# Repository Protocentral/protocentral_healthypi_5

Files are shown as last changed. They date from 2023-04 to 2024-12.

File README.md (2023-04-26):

# HealthyPi 5 

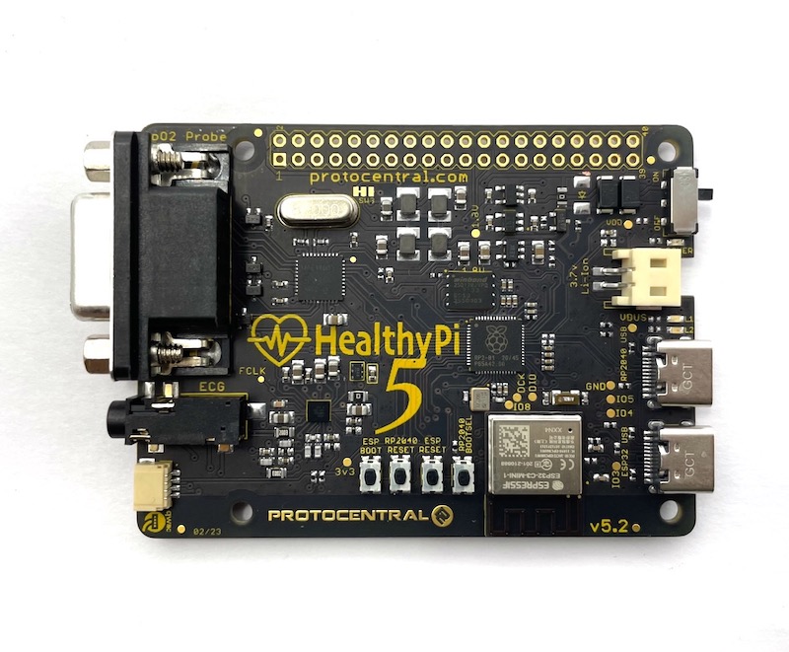
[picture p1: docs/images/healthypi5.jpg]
HealthyPi 5


Don't have one? You can pre-order now at [Crowd Supply](https://www.crowdsupply.com/protocentral/healthypi-5)

HealthyPi 5 is the latest evolution of the HealthyPi series. It is a robust, feature-rich, open-source development board that allows you to explore many different biosignals with minimal effort. Whether you need a simple monitor for a specific vital sign or a complete health-sensor platform, HealthyPi 5 is an extensible solution to to your health-data challenges. Out of the box, it can handle electrocardiogram (ECG), respiration, photoplethysmography (PPG), oxygen saturation (SpO₂), and body temperature data. And it’s easy to upgrade as well! Using the Qwiic connectors on the Pro-Carrier Board, you can leverage external sensor modules to capture and analyze additional biosignals, such as galvanic skin response (GSR), electroencephalogram (EEG), and electromyogram (EMG) data.

## Features

* RP2040 dual-core ARM Cortex M0 microcontroller
* ESP32C3 RISC-V module with BLE and Wi-Fi support
* MAX30001 analog front end for ECG and respiration measurement
* AFE4400 analog front end for PPG
* MAX30205 temperature sensor via onboard Qwiic/I²C connectors
* 40-pin Raspberry Pi HAT connector (also used to connect our Display Add-On Module)
* 1x USB Type-C connector for communication with a computer and programming the RP2040
* 1x USB Type-C connector for programming and debugging the ESP32 module
* Onboard MicroSD card slot
* On-board Li-Ion battery management with charging through USB

## Repository Contents

* /gui - Processing GUI for HealthyPi 5
* /hardware - Eagle design files (.brd, .sch, pdfs)
* /python - Python scripts for HealthyPi 5 (_Work in Progress_)
* If you're looking for the firmware for the HealthyPi 5, it's located in its own repository [here](https://github.com/Protocentral/protocentral_healthypi_5_firmware).

## License Information

This product is open source! Please see the LICENSE.md file for more information.

## Getting Started
_Getting Started Guide coming soon..._

## License Information

License

This product is open source! Both, our hardware and software are open source and licensed under the following licenses:

Hardware
---------

**All hardware is released under the [CERN-OHL-P v2](https://ohwr.org/cern_ohl_p_v2.txt)** license.

Copyright CERN 2020.

This source describes Open Hardware and is licensed under the CERN-OHL-P v2.

You may redistribute and modify this documentation and make products
using it under the terms of the CERN-OHL-P v2 (https:/cern.ch/cern-ohl).
This documentation is distributed WITHOUT ANY EXPRESS OR IMPLIED
WARRANTY, INCLUDING OF MERCHANTABILITY, SATISFACTORY QUALITY
AND FITNESS FOR A PARTICULAR PURPOSE. Please see the CERN-OHL-P v2
for applicable conditions

Software
--------

**All software is released under the MIT License(http://opensource.org/licenses/MIT).**

THE SOFTWARE IS PROVIDED "AS IS", WITHOUT WARRANTY OF ANY KIND, EXPRESS OR IMPLIED, INCLUDING BUT NOT LIMITED TO THE WARRANTIES OF MERCHANTABILITY, FITNESS FOR A PARTICULAR PURPOSE AND NONINFRINGEMENT. IN NO EVENT SHALL THE AUTHORS OR COPYRIGHT HOLDERS BE LIABLE FOR ANY CLAIM, DAMAGES OR OTHER LIABILITY, WHETHER IN AN ACTION OF CONTRACT, TORT OR OTHERWISE, ARISING FROM, OUT OF OR IN CONNECTION WITH THE SOFTWARE OR THE USE OR OTHER DEALINGS IN THE SOFTWARE.

Documentation
-------------
**All documentation is released under [Creative Commons Share-alike 4.0 International](http://creativecommons.org/licenses/by-sa/4.0/).**


You are free to:

* Share — copy and redistribute the material in any medium or format
* Adapt — remix, transform, and build upon the material for any purpose, even commercially.
The licensor cannot revoke these freedoms as long as you follow the license terms.

Under the following terms:

* Attribution — You must give appropriate credit, provide a link to the license, and indicate if changes were made. You may do so in any reasonable manner, but not in any way that suggests the licensor endorses you or your use.
* ShareAlike — If you remix, transform, or build upon the material, you must distribute your contributions under the same license as the original.

Please check [*LICENSE.md*](LICENSE.md) for detailed license descriptions.

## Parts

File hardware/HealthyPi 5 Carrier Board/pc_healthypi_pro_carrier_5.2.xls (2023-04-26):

healthpi_pro_carrier
Qty | Value | Parts | Package
2 | 100n | C3, C4 | C0402
2 | 100nF | C8, C11 | C0402
4 | 4.7u | C1, C2, C14, C16 | C0805
1 | 0R | R77 | R0805
2 | 10K | R7, R33 | R0402
2 | 5.1K | R3, R4 | R0402
3 | DNP | R9, R10, R11 | R0402
1 | INDUCTOR-82153C | U$45 | INDUCTOR-8200
1 | ISOUSB111DWXR | U$1 | SSOP-16-5.85X7.5
1 | NXJ2S0505MC | U$5 | NXJ2S0505MC
6 | PESD0402-0402 | D1, D2, D3, D4, D5, D6 | 402
1 | PIN20X2 | K1 | PIN_20X2
6 | QWIIC_RIGHT_ANGLE | J1, J2, J3, J5, J6, J7 | JST04_1MM_RA
5 | TBD | R1, R2, R5, R6, R8 | R0402
1 | TCR2EF33,LM(CT | U9 | SOT23-5
1 | USB4105-GF-A | J4 | USB-C-16P

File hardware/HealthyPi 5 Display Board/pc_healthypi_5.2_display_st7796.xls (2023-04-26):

pc_healthypi_5.2_display
Qty | Value | Parts | Package
1 | 100nF | C5 | C0402
2 | 10uF | C3, C4 | 0805-NO
1 | 1uF | C1 | 0805-NO
1 | 0R | R4 | R0402
1 | 0R | R7 | R0805
1 | 100K | R5 | 0805-NO
2 | 10K | R10, R12 | R0402
1 | 1K | R9 | R0402
3 | 1k | R8, R21, R44 | 402
2 | 330R | R2, R3 | R0402
1 | BC847 | T1 | SOT23-BEC
1 | BLUE | POWER1 | CHIPLED_0603
3 | DNP | R1, R6, R11 | R0402
1 | FPC40 | U$10 | FPC40PIN
1 | MEM2051-00-195-00-A | J1 | GCT_MEM2051-00-195-00-A
1 | NAV_SWITCH | S1 | NAV_SWITCH
1 | OS102011MA1QN1 | S3 | OS102011MA1QN1
1 | PIN20X2SMT | K1 | 20X2SMT
1 | RED | CHG2 | CHIPLED_0603

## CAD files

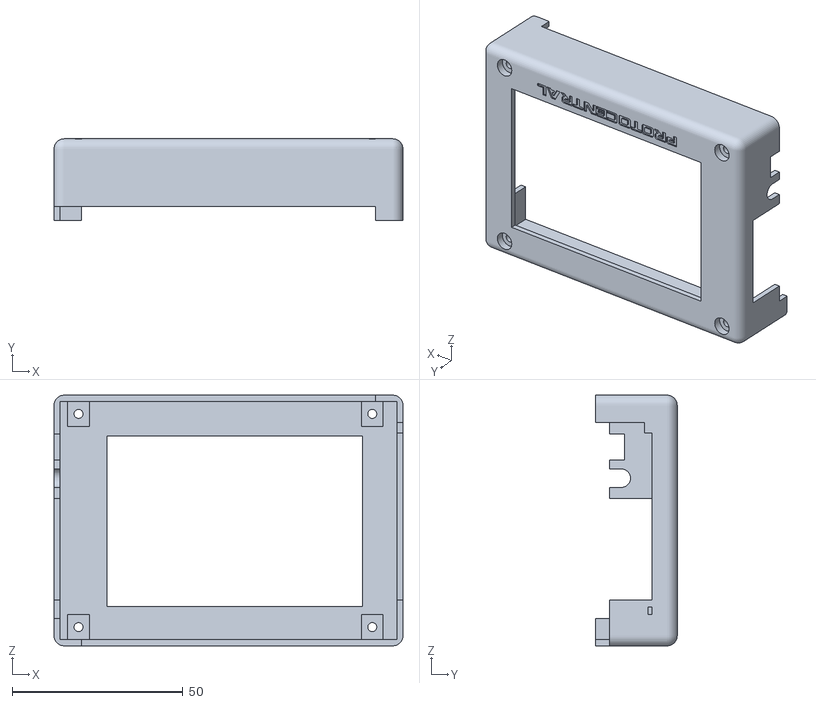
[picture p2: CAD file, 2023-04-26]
hardware/HealthyPi 5 Enclosure/HealthyPi 5 - Enclosure - Top.stl
102.3 x 23.9 x 73.5

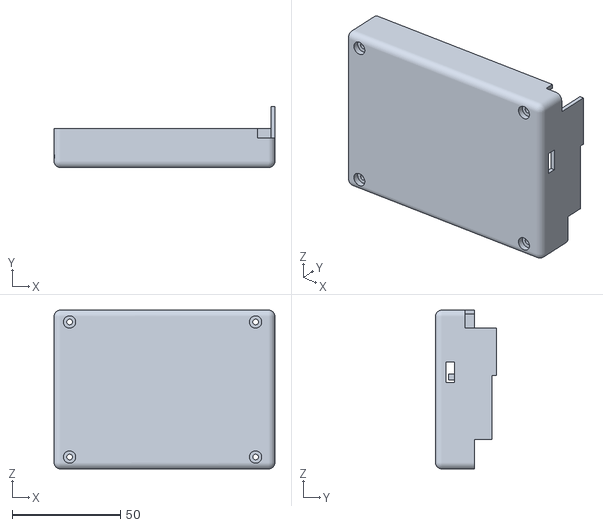
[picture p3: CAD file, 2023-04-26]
hardware/HealthyPi 5 Enclosure/HealthyPi 5 - Enclosure - Bottom.stl
102.3 x 28.3 x 73.5

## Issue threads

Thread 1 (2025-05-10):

PPG sample rate

selfinmotion, 2025-05-10:
What is the maximum sample rate for capture of PPG data this board is capable of? It seems to be missing from the specifications. Thank you.

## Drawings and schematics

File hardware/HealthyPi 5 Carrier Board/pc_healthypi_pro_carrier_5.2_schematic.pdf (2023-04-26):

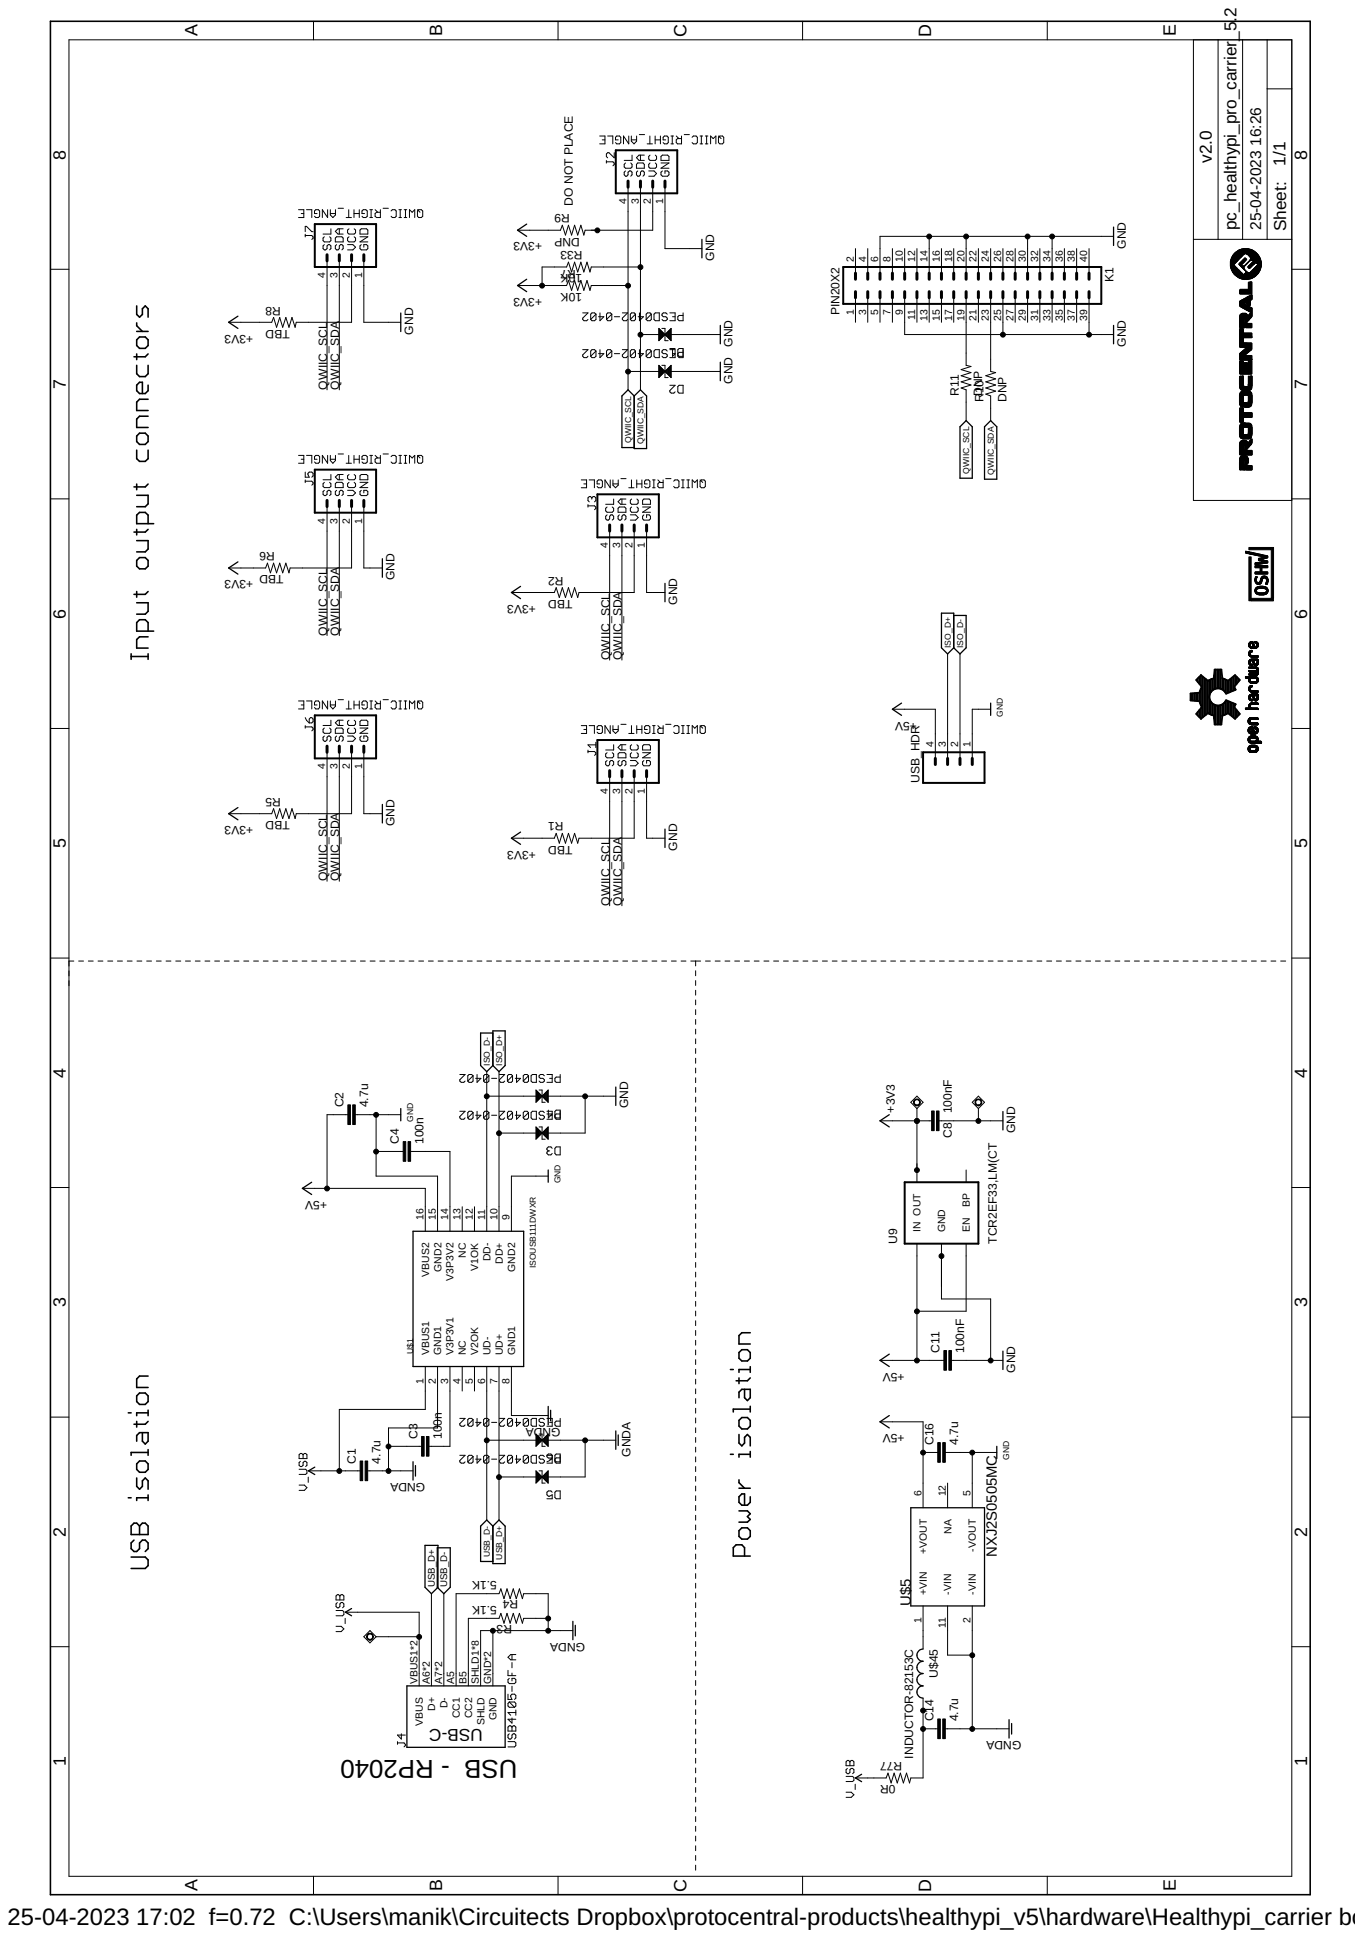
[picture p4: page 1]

25-04-2023 17:02 f=0.72 C:\Users\manik\Circuitects Dropbox\protocentral-products\healthypi_v5\hardware\Healthypi_carrier board\Carrier main board\pc_healthypi_pro_carrier_5.2.sch (Sheet: 1/1)

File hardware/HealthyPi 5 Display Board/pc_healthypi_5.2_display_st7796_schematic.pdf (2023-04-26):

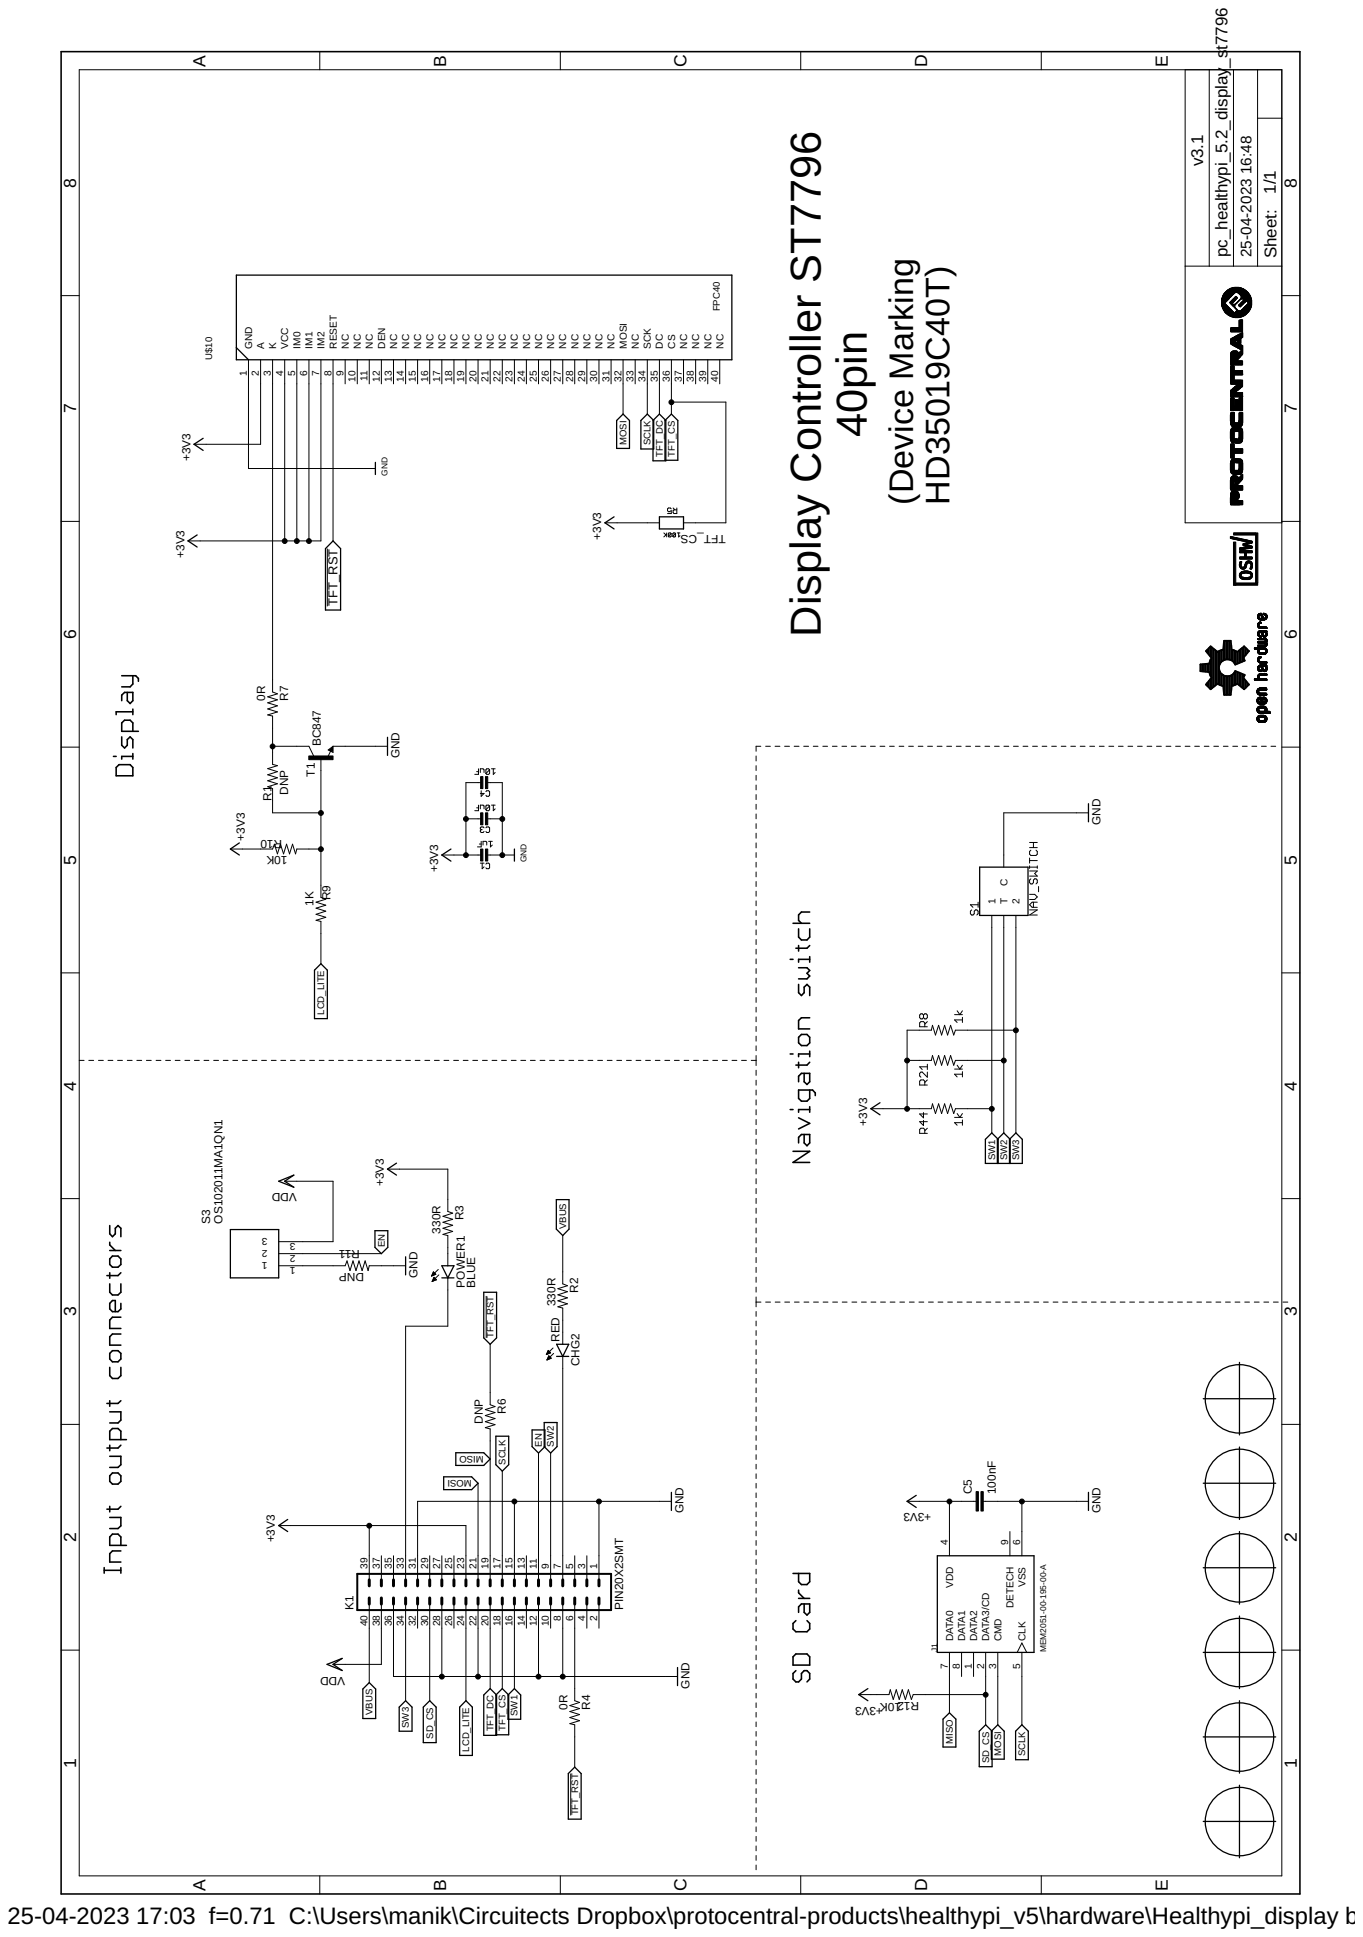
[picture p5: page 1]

25-04-2023 17:03 f=0.71 C:\Users\manik\Circuitects Dropbox\protocentral-products\healthypi_v5\hardware\Healthypi_display board\pc_healthypi_5.2_display_st7796.sch (Sheet: 1/1)

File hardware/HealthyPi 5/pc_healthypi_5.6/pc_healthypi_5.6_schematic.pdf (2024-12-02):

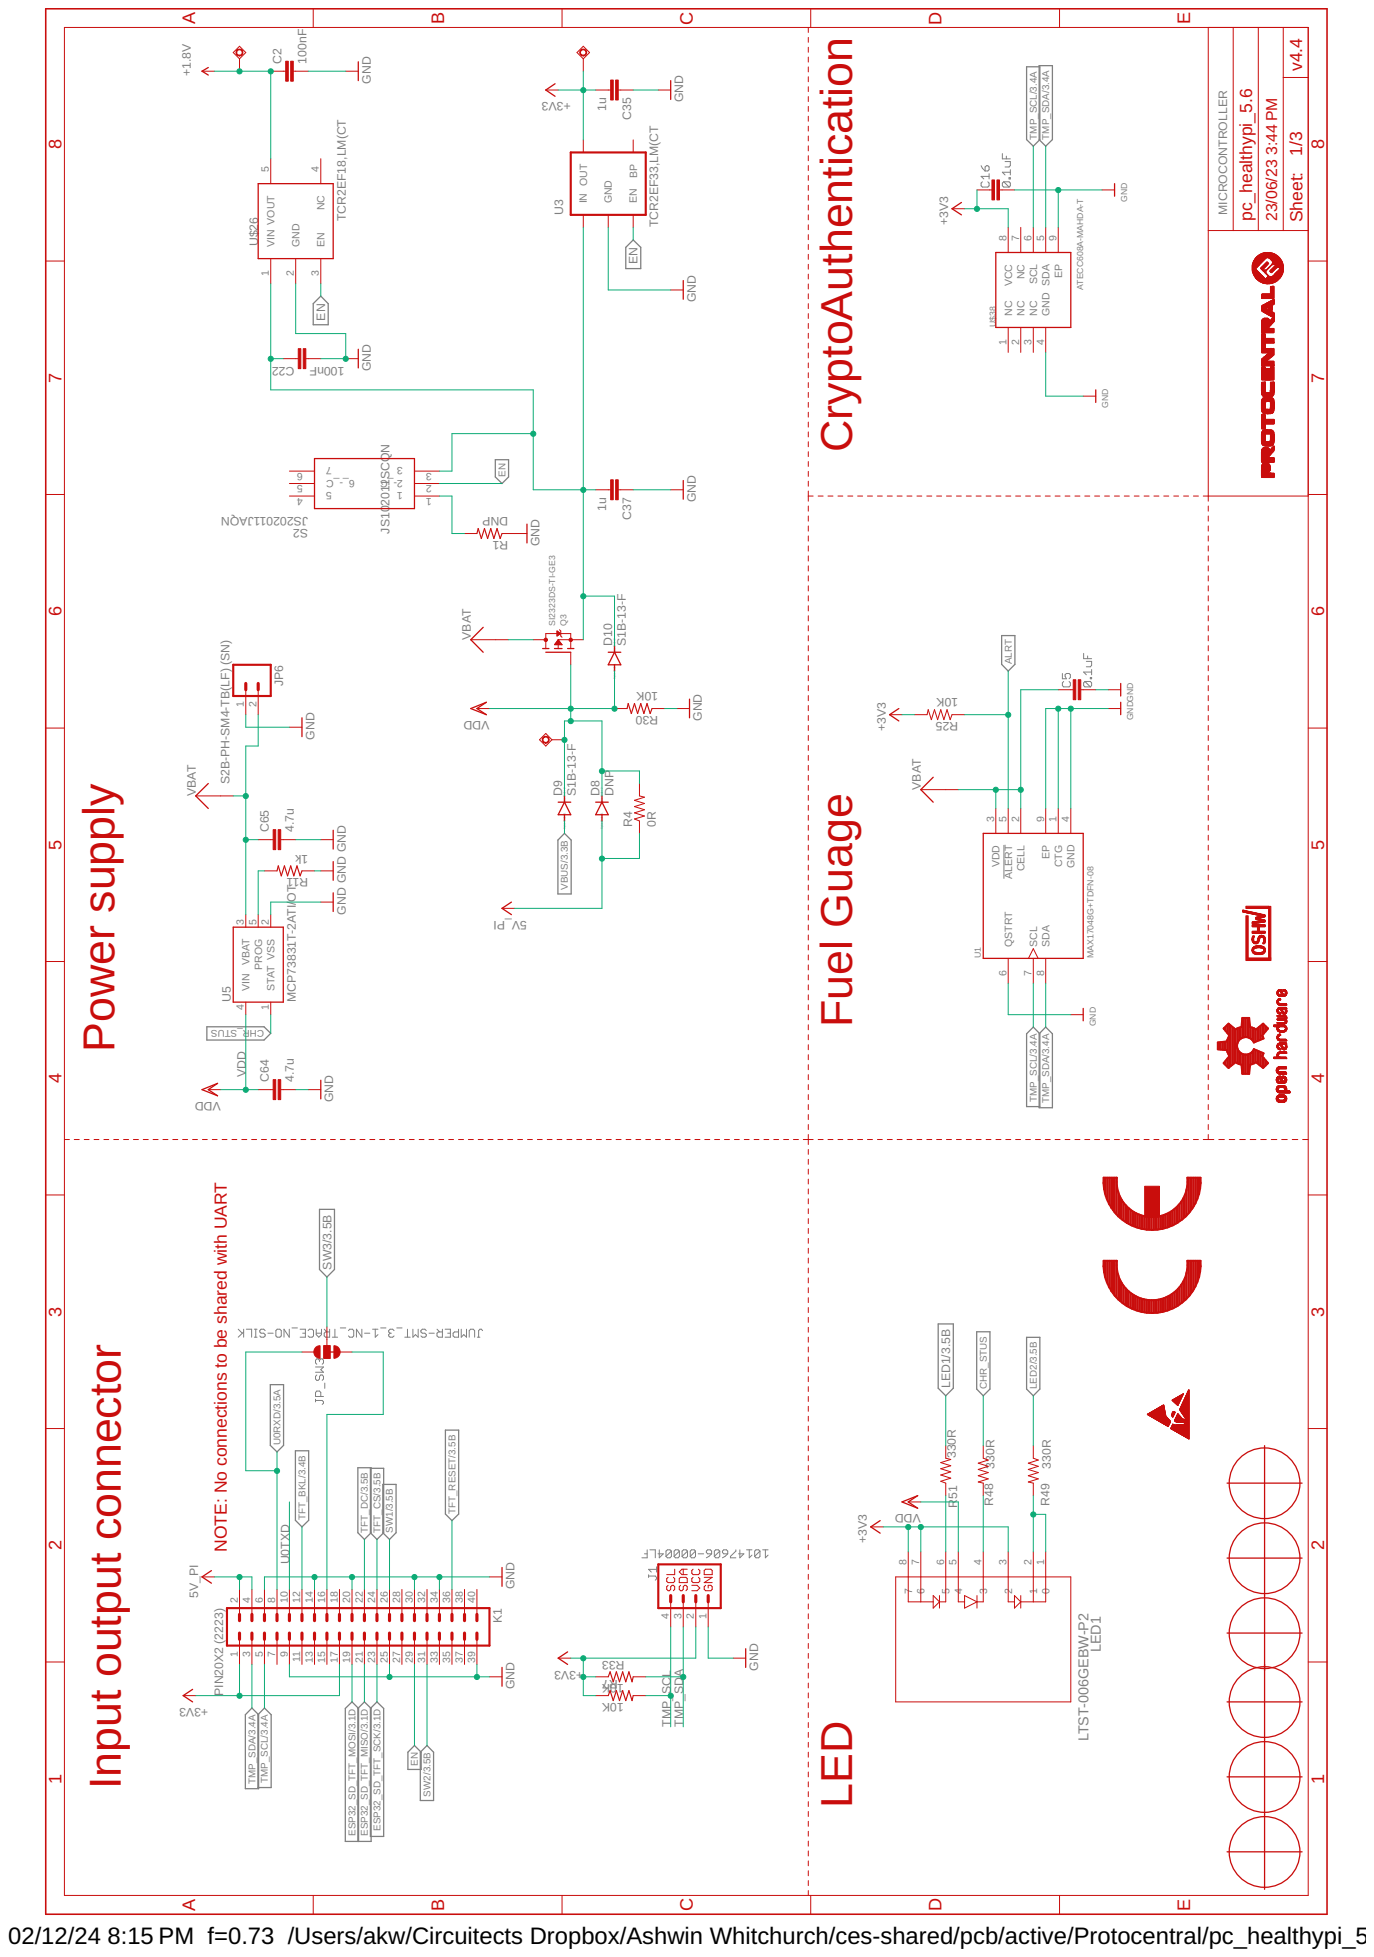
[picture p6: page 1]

S2B-PH-SM4-TB(LF) (SN) GND

MCP73831T-2ATI/OT 4.7u 4.7u GND GND GND

NOTE: No connections to be shared with UART

02/12/24 8:15 PM f=0.73 /Users/akw/Circuitects Dropbox/Ashwin Whitchurch/ces-shared/pcb/active/Protocentral/pc_healthypi_5.6/pc_healthypi_5.6.sch (Sheet: 1/3)

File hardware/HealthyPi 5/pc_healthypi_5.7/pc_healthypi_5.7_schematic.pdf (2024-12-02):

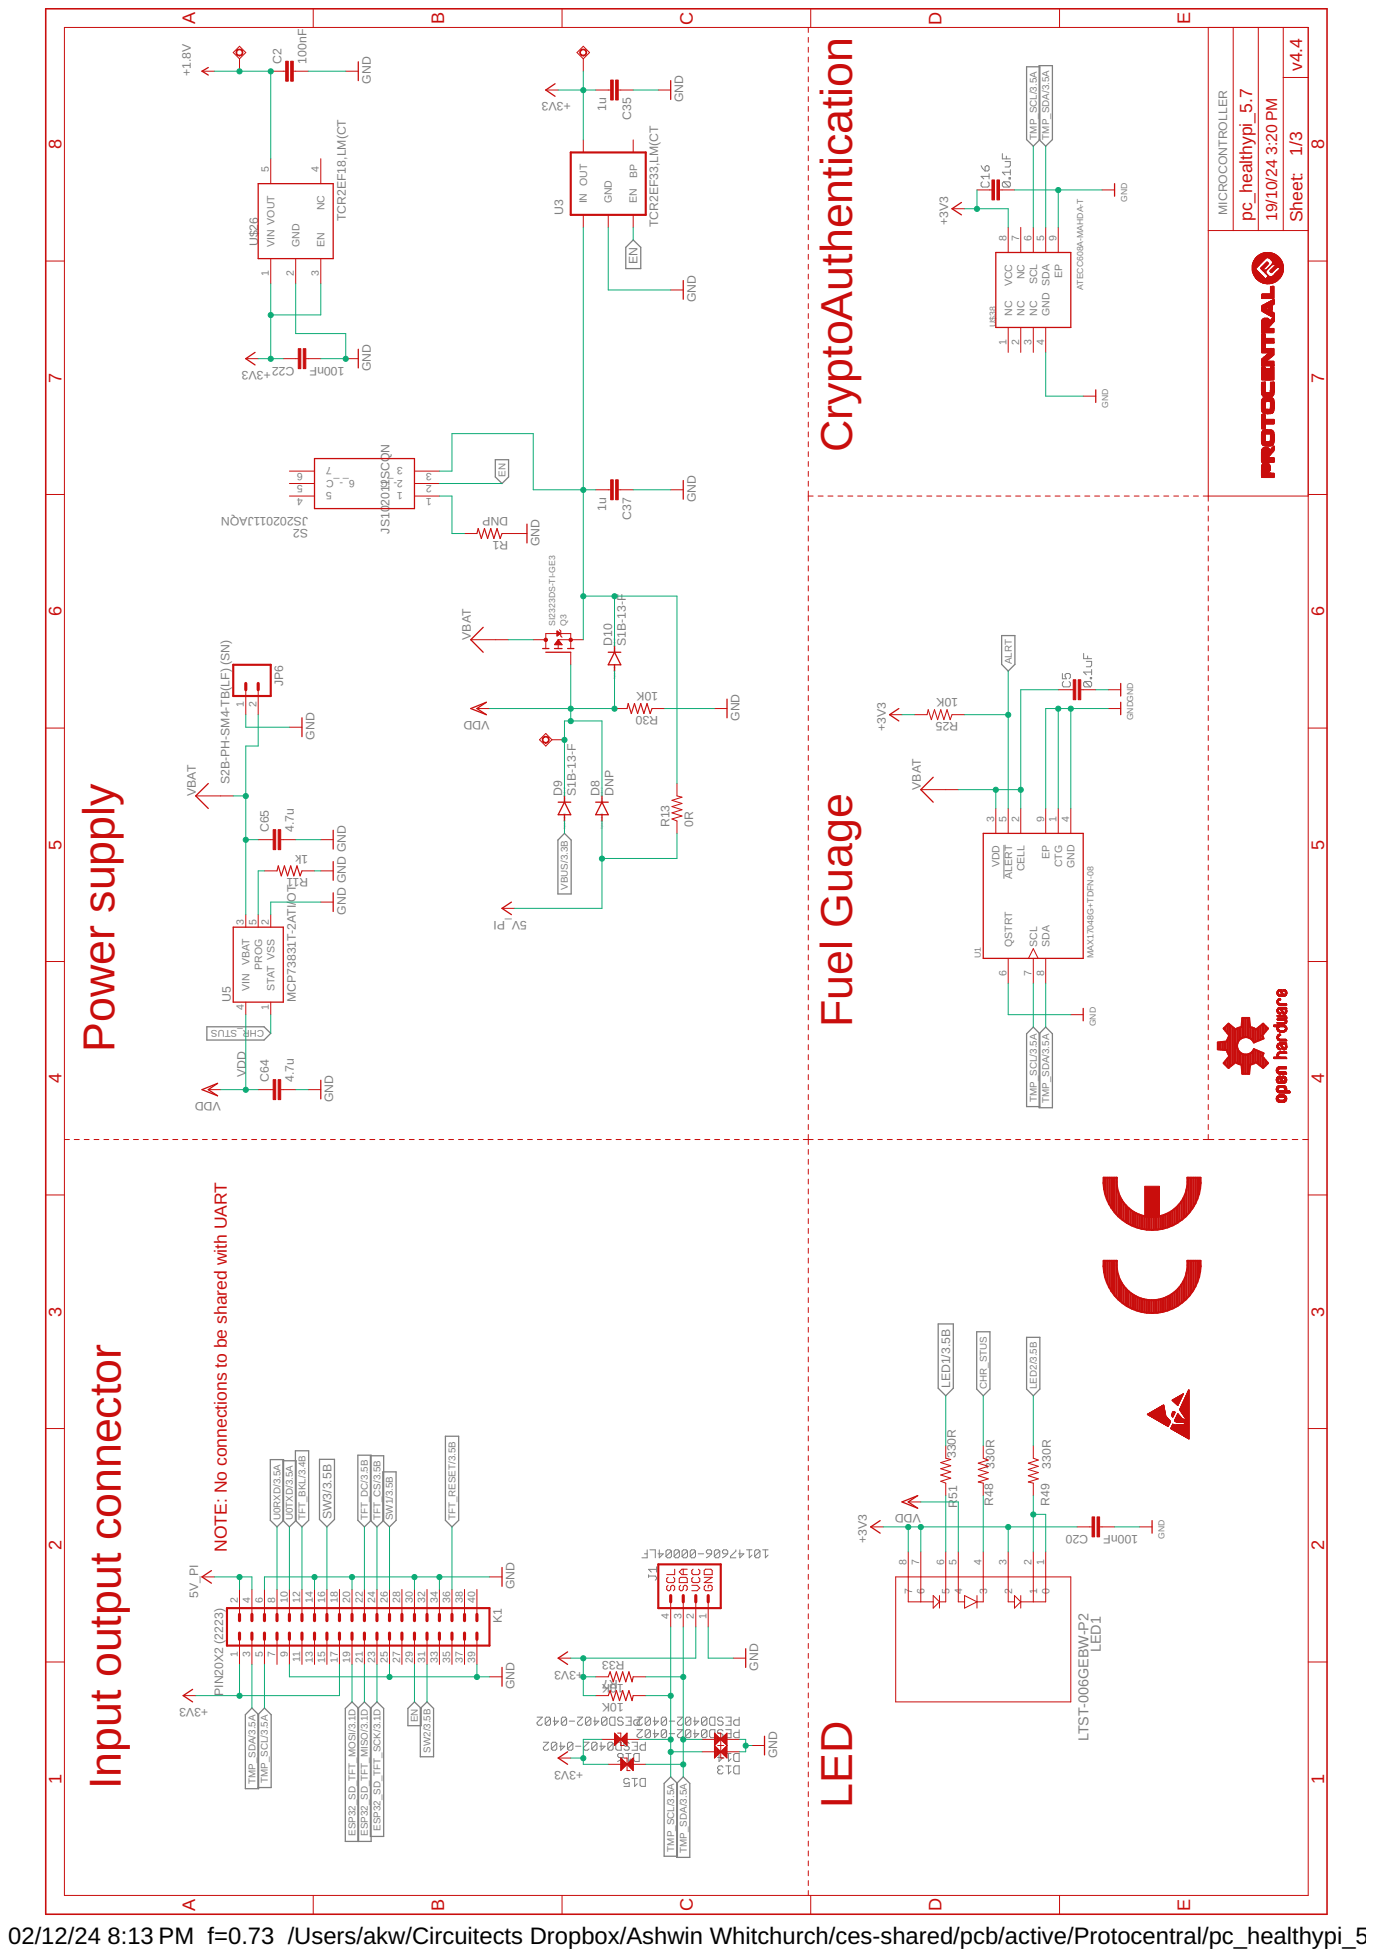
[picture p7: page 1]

S2B-PH-SM4-TB(LF) (SN) GND

MCP73831T-2ATI/OT 4.7u 4.7u GND GND GND

NOTE: No connections to be shared with UART

02/12/24 8:13 PM f=0.73 /Users/akw/Circuitects Dropbox/Ashwin Whitchurch/ces-shared/pcb/active/Protocentral/pc_healthypi_5.7/pc_healthypi_5.7.sch (Sheet: 1/3)

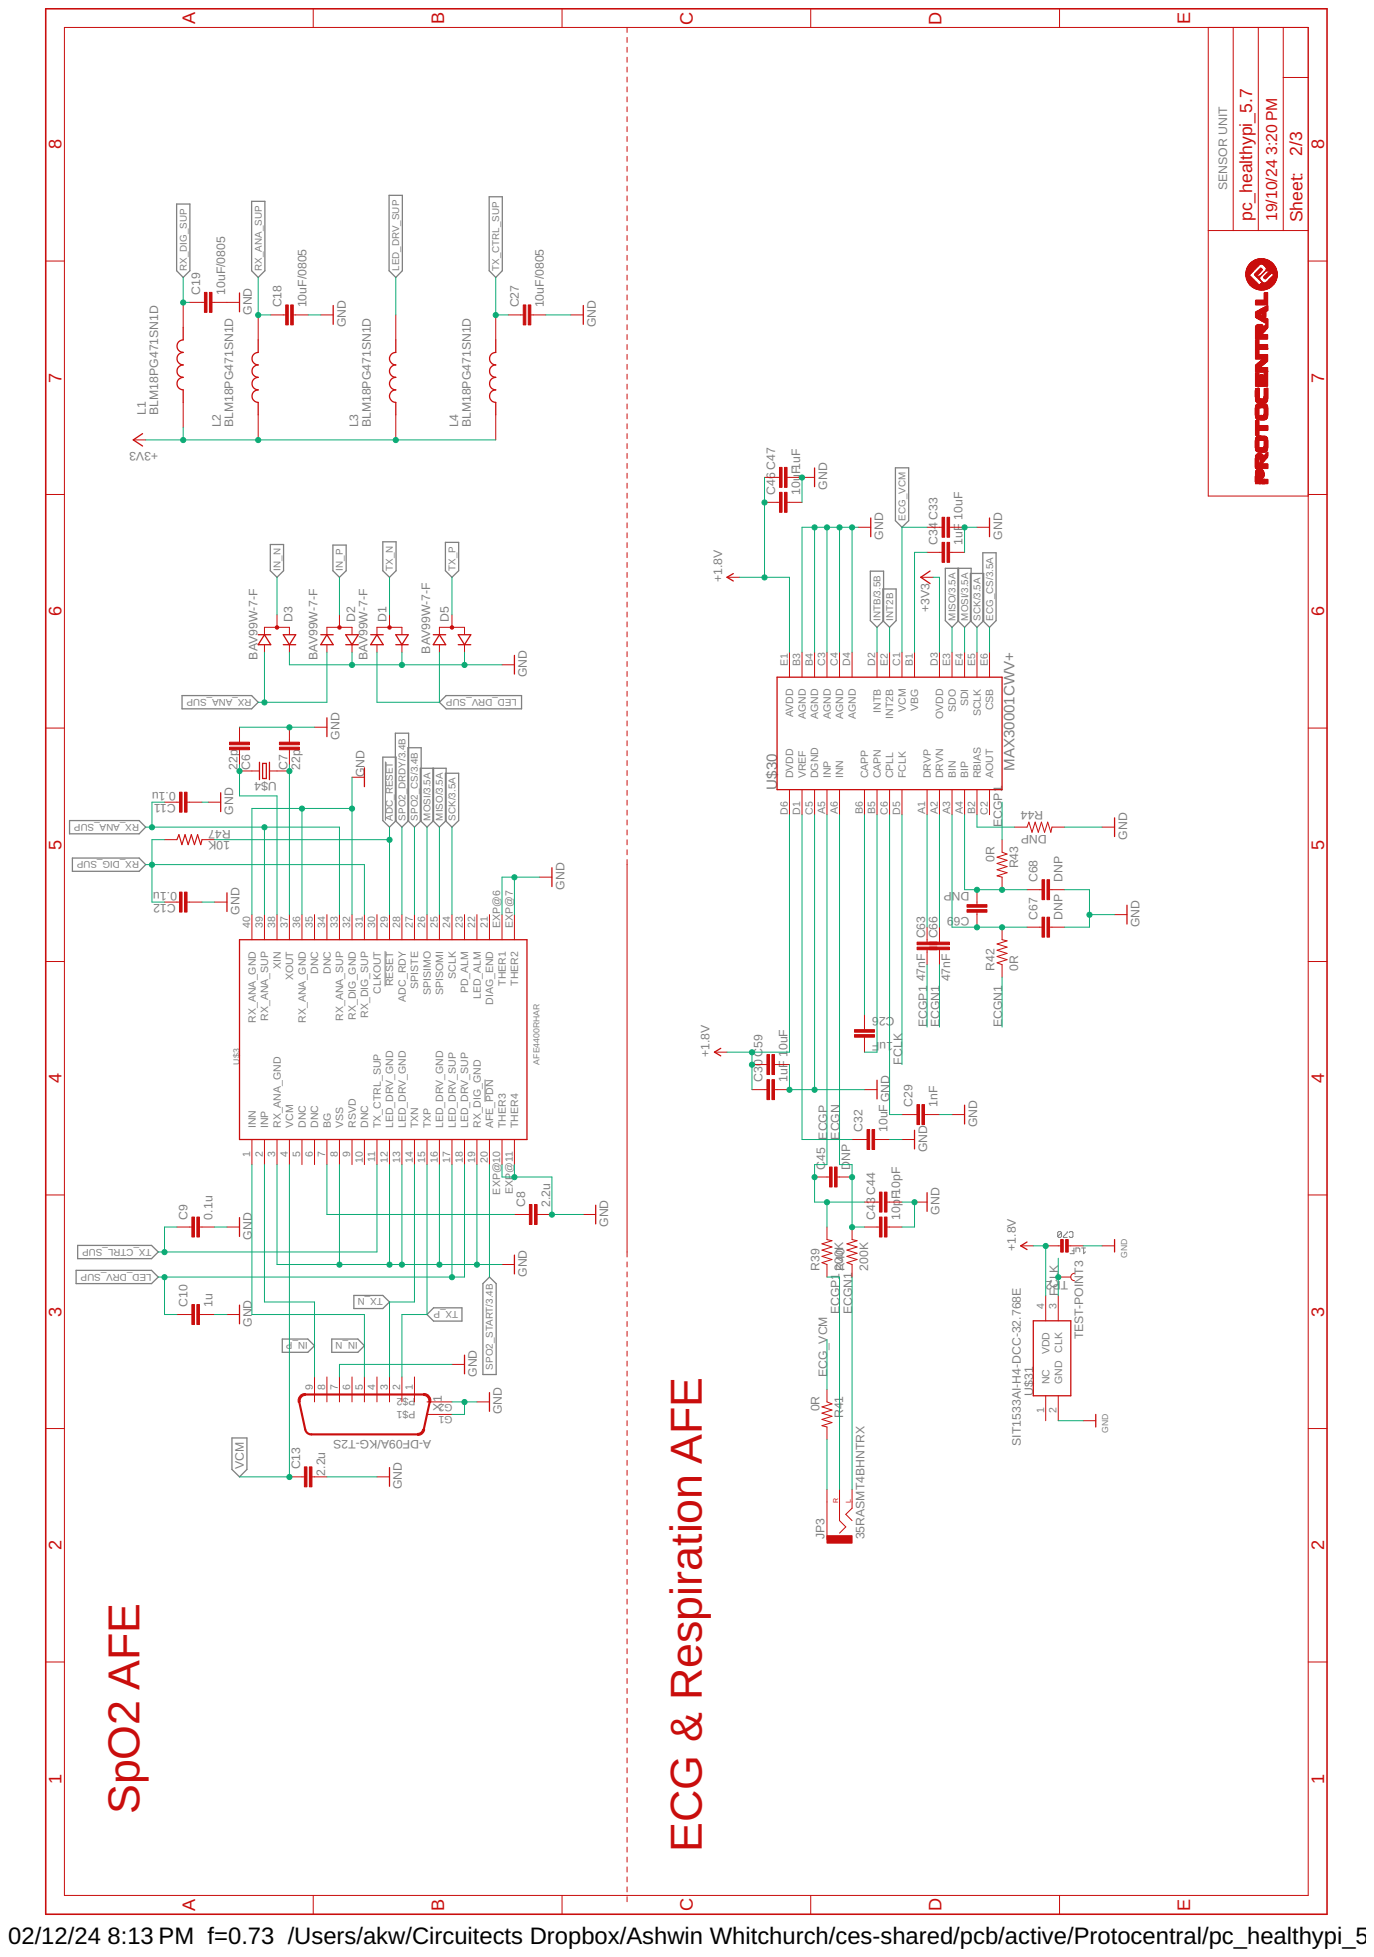
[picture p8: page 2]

THER1 EXP@6 THER2 EXP@7 THER3 EXP@10 THER4 EXP@11

02/12/24 8:13 PM f=0.73 /Users/akw/Circuitects Dropbox/Ashwin Whitchurch/ces-shared/pcb/active/Protocentral/pc_healthypi_5.7/pc_healthypi_5.7.sch (Sheet: 2/3)

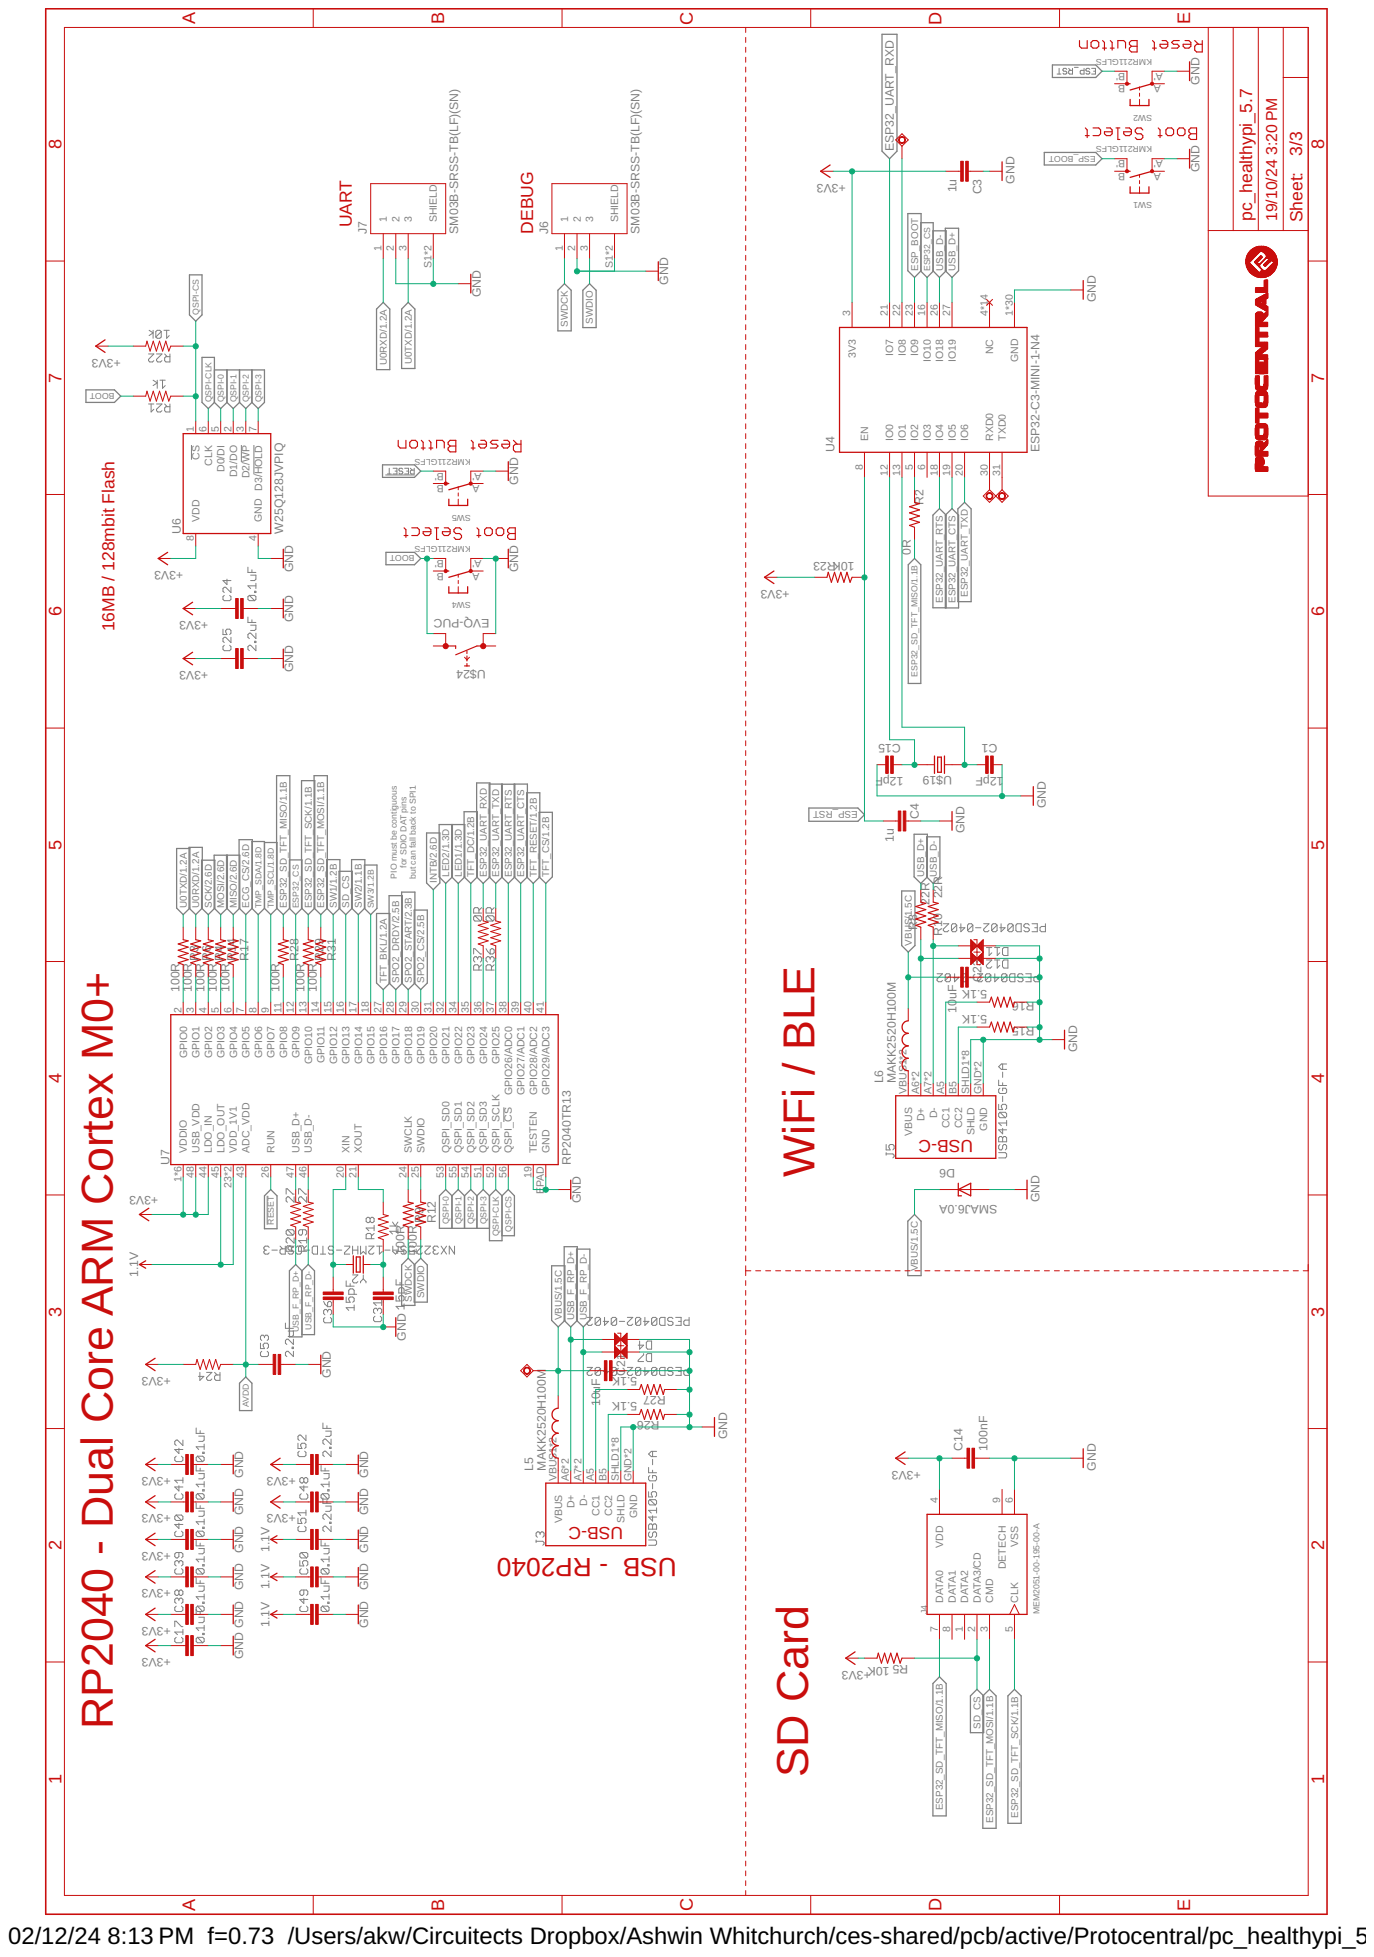
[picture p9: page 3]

SM03B-SRSS-TB(LF)(SN) GND

PIO must be contiguous

for SDIO DAT pins but can fall back to SPI1 GND

GND GND GND GND GND

02/12/24 8:13 PM f=0.73 /Users/akw/Circuitects Dropbox/Ashwin Whitchurch/ces-shared/pcb/active/Protocentral/pc_healthypi_5.7/pc_healthypi_5.7.sch (Sheet: 3/3)

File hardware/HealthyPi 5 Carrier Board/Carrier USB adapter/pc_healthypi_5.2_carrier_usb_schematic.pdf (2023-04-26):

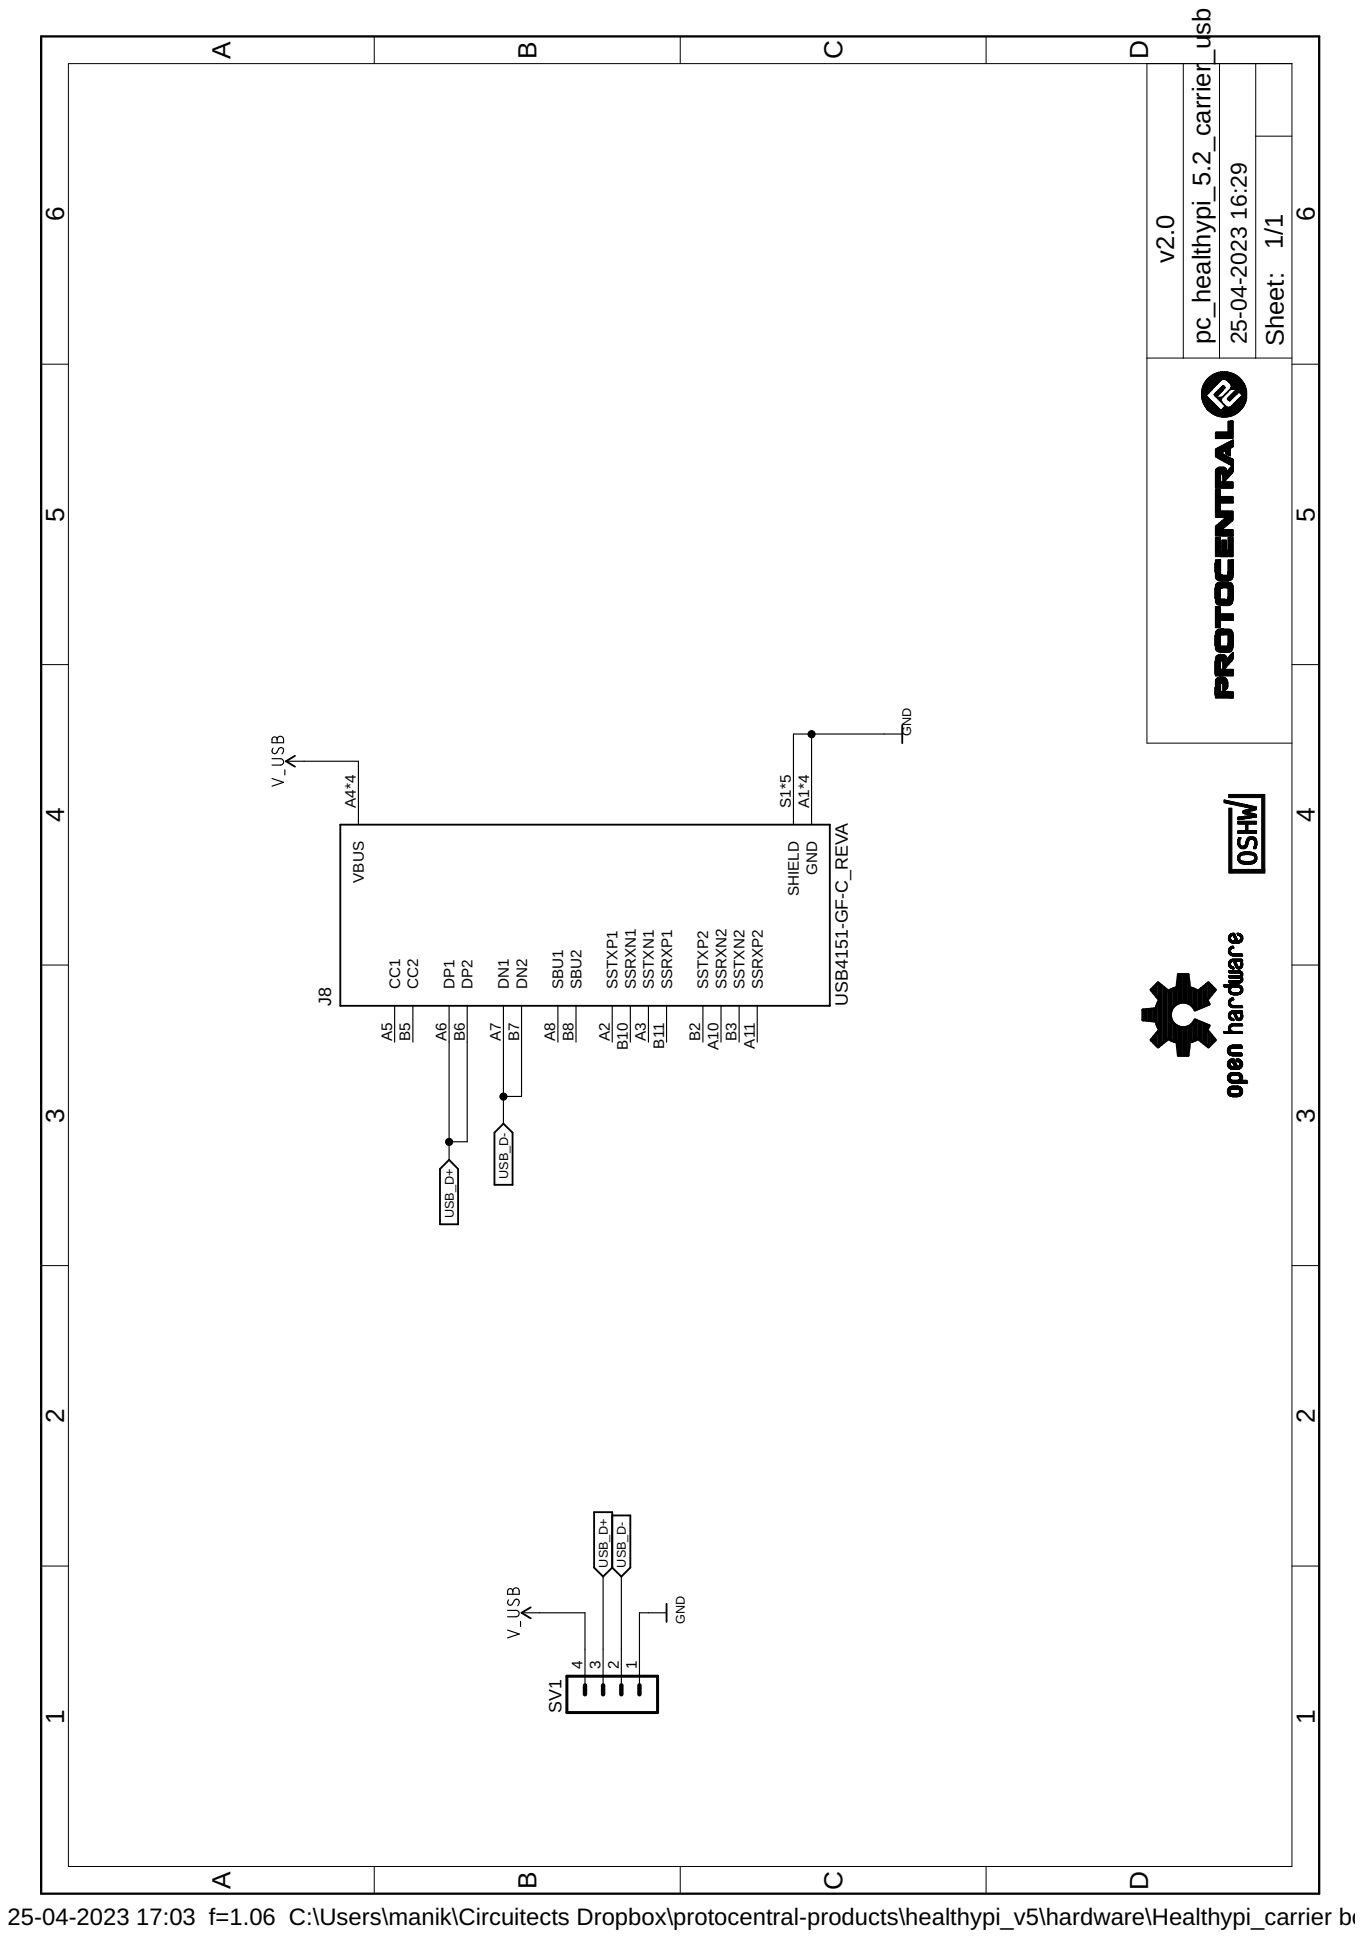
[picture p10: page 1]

25-04-2023 17:03 f=1.06 C:\Users\manik\Circuitects Dropbox\protocentral-products\healthypi_v5\hardware\Healthypi_carrier board\Carrier USB adapter\pc_healthypi_5.2_carrier_usb.sch (Sheet: 1/1)

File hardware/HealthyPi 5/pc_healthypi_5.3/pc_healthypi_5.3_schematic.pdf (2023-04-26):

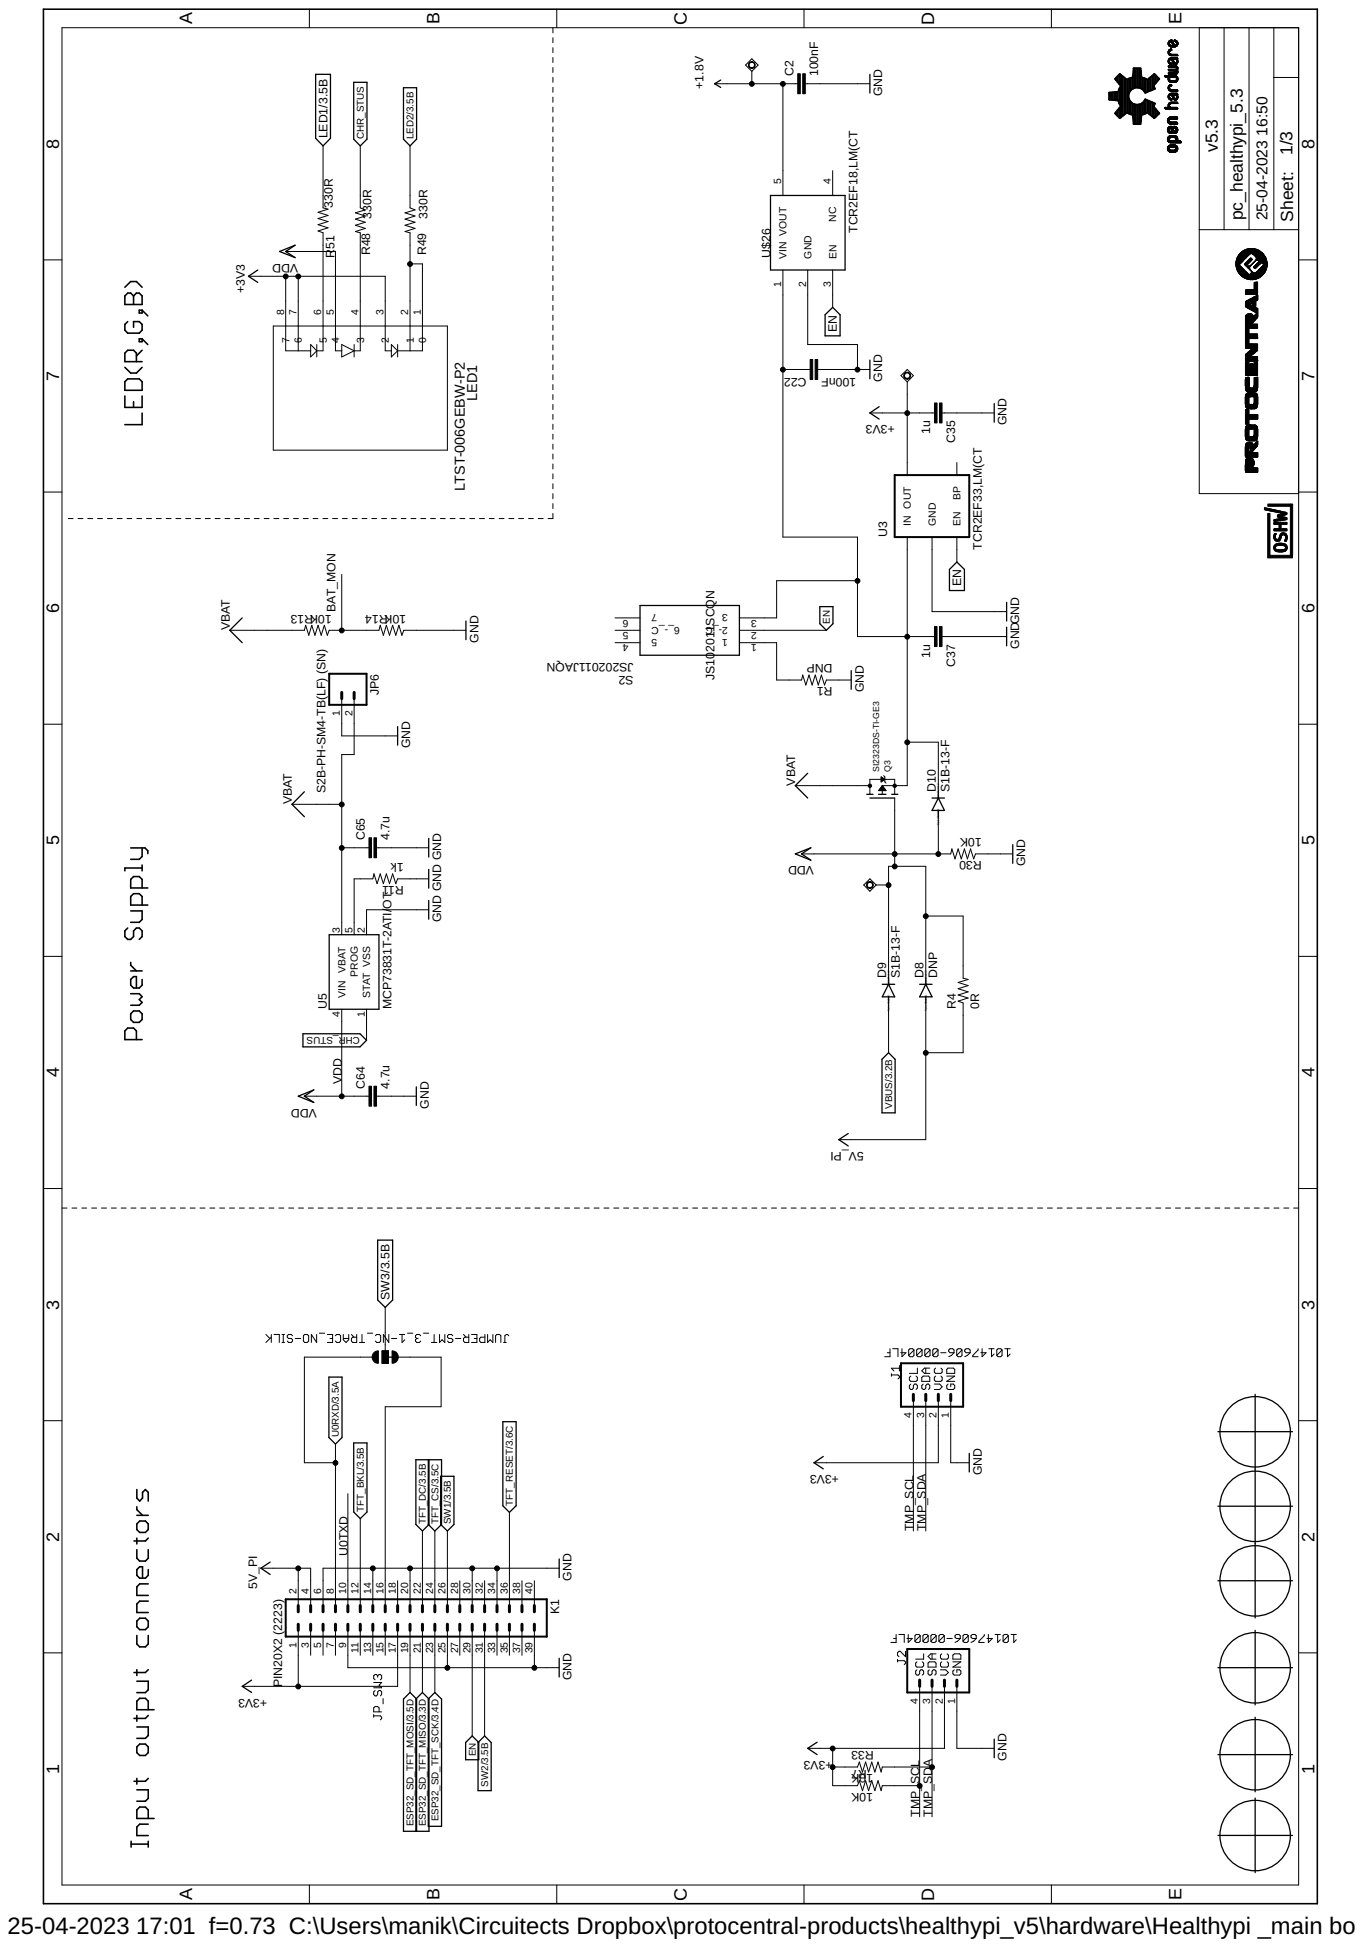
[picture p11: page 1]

S2B-PH-SM4-TB(LF) (SN) GND

MCP73831T-2ATI/OT 4.7u 4.7u GND GND GND

25-04-2023 17:01 f=0.73 C:\Users\manik\Circuitects Dropbox\protocentral-products\healthypi_v5\hardware\Healthypi _main board\pc_healthypi_5.3.sch (Sheet: 1/3)

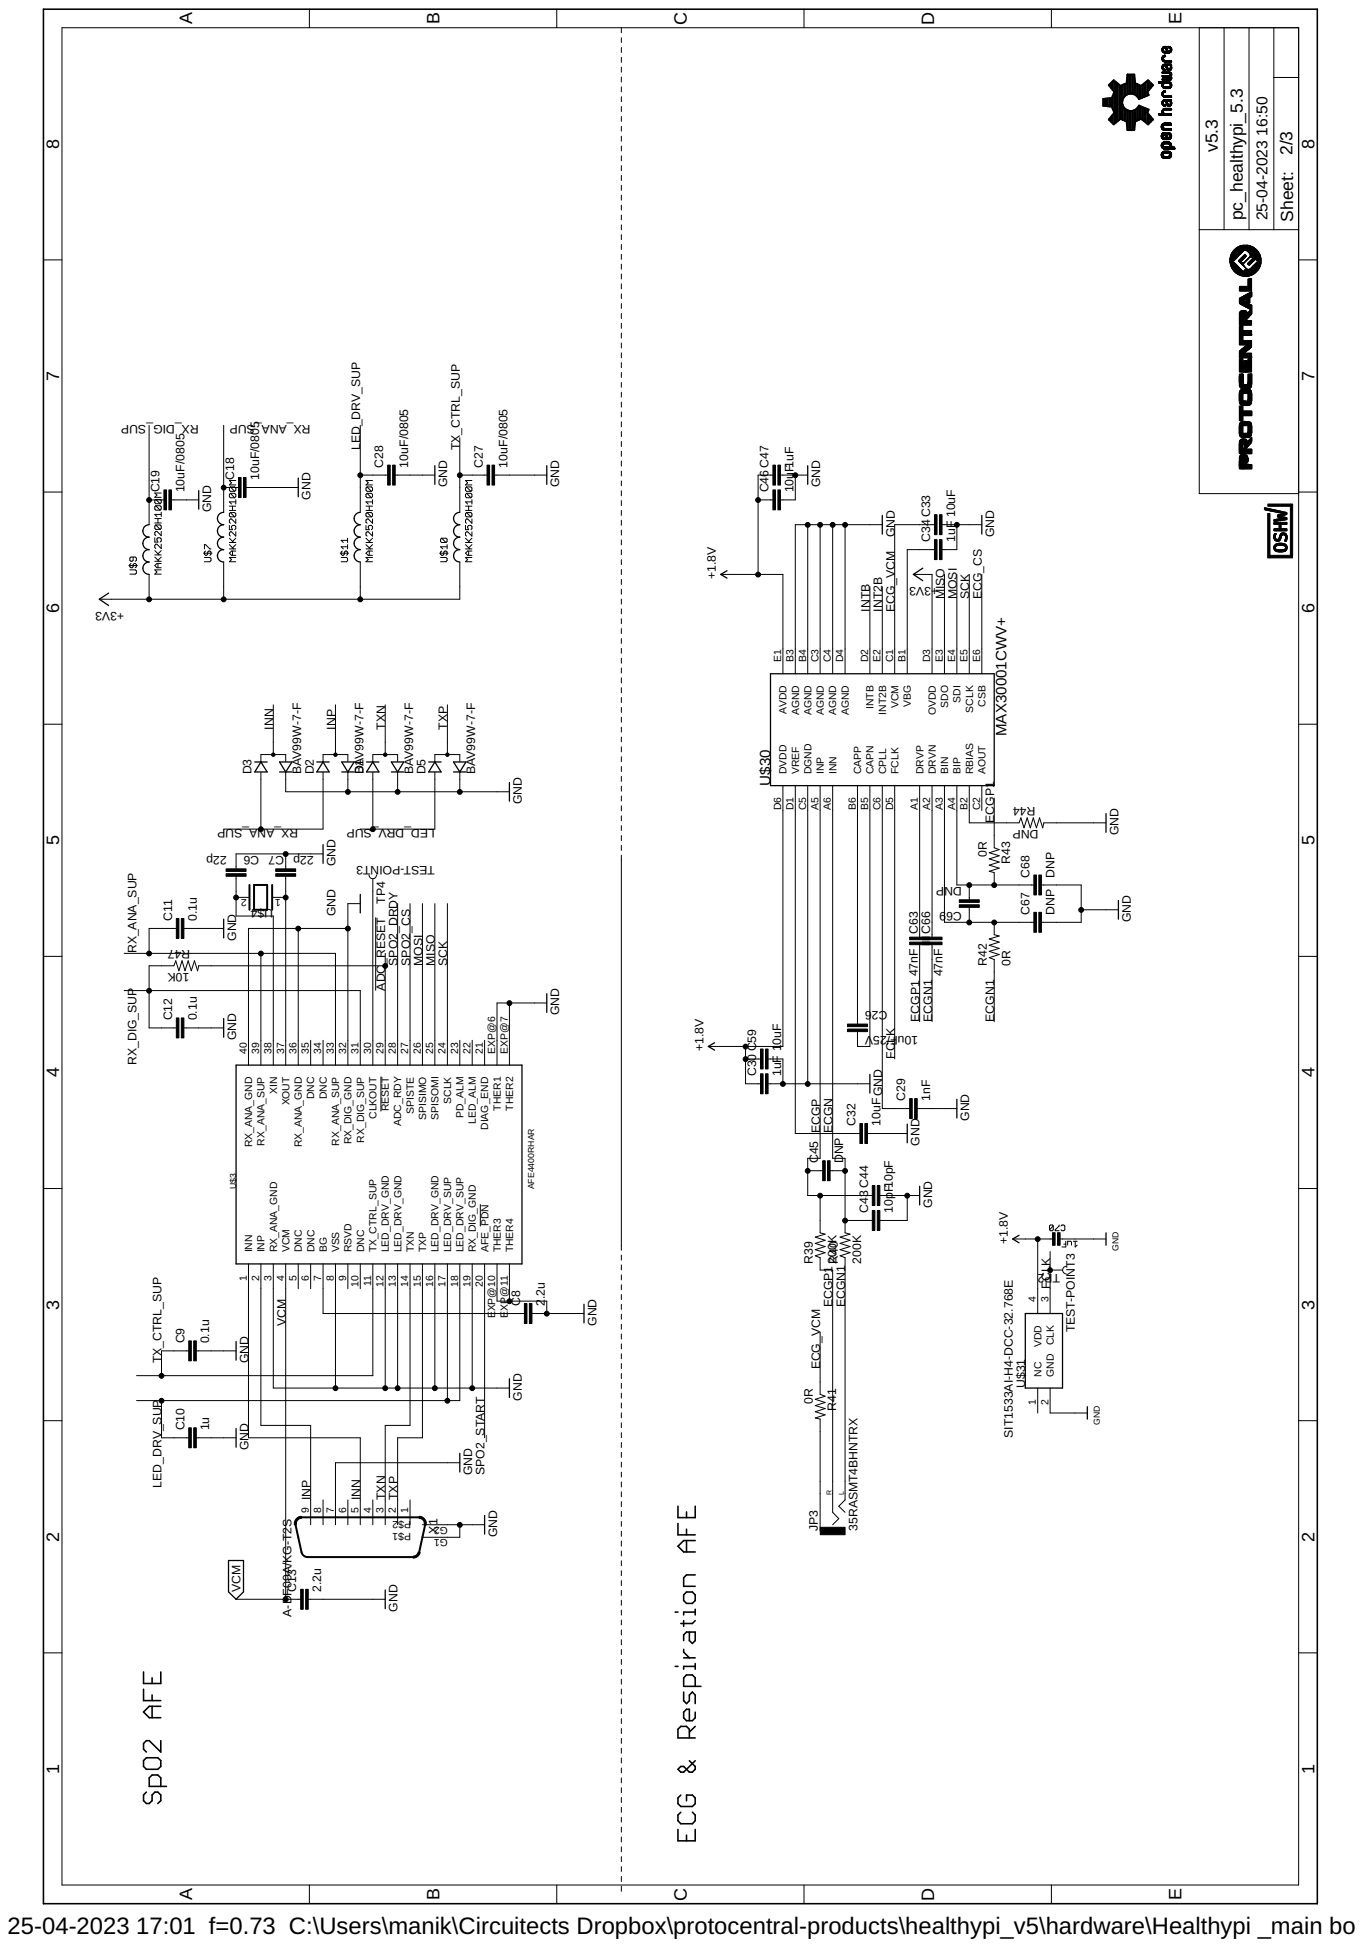
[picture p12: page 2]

THER1 EXP@6 THER2 EXP@7 THER3 EXP@10 THER4 EXP@11

25-04-2023 17:01 f=0.73 C:\Users\manik\Circuitects Dropbox\protocentral-products\healthypi_v5\hardware\Healthypi _main board\pc_healthypi_5.3.sch (Sheet: 2/3)

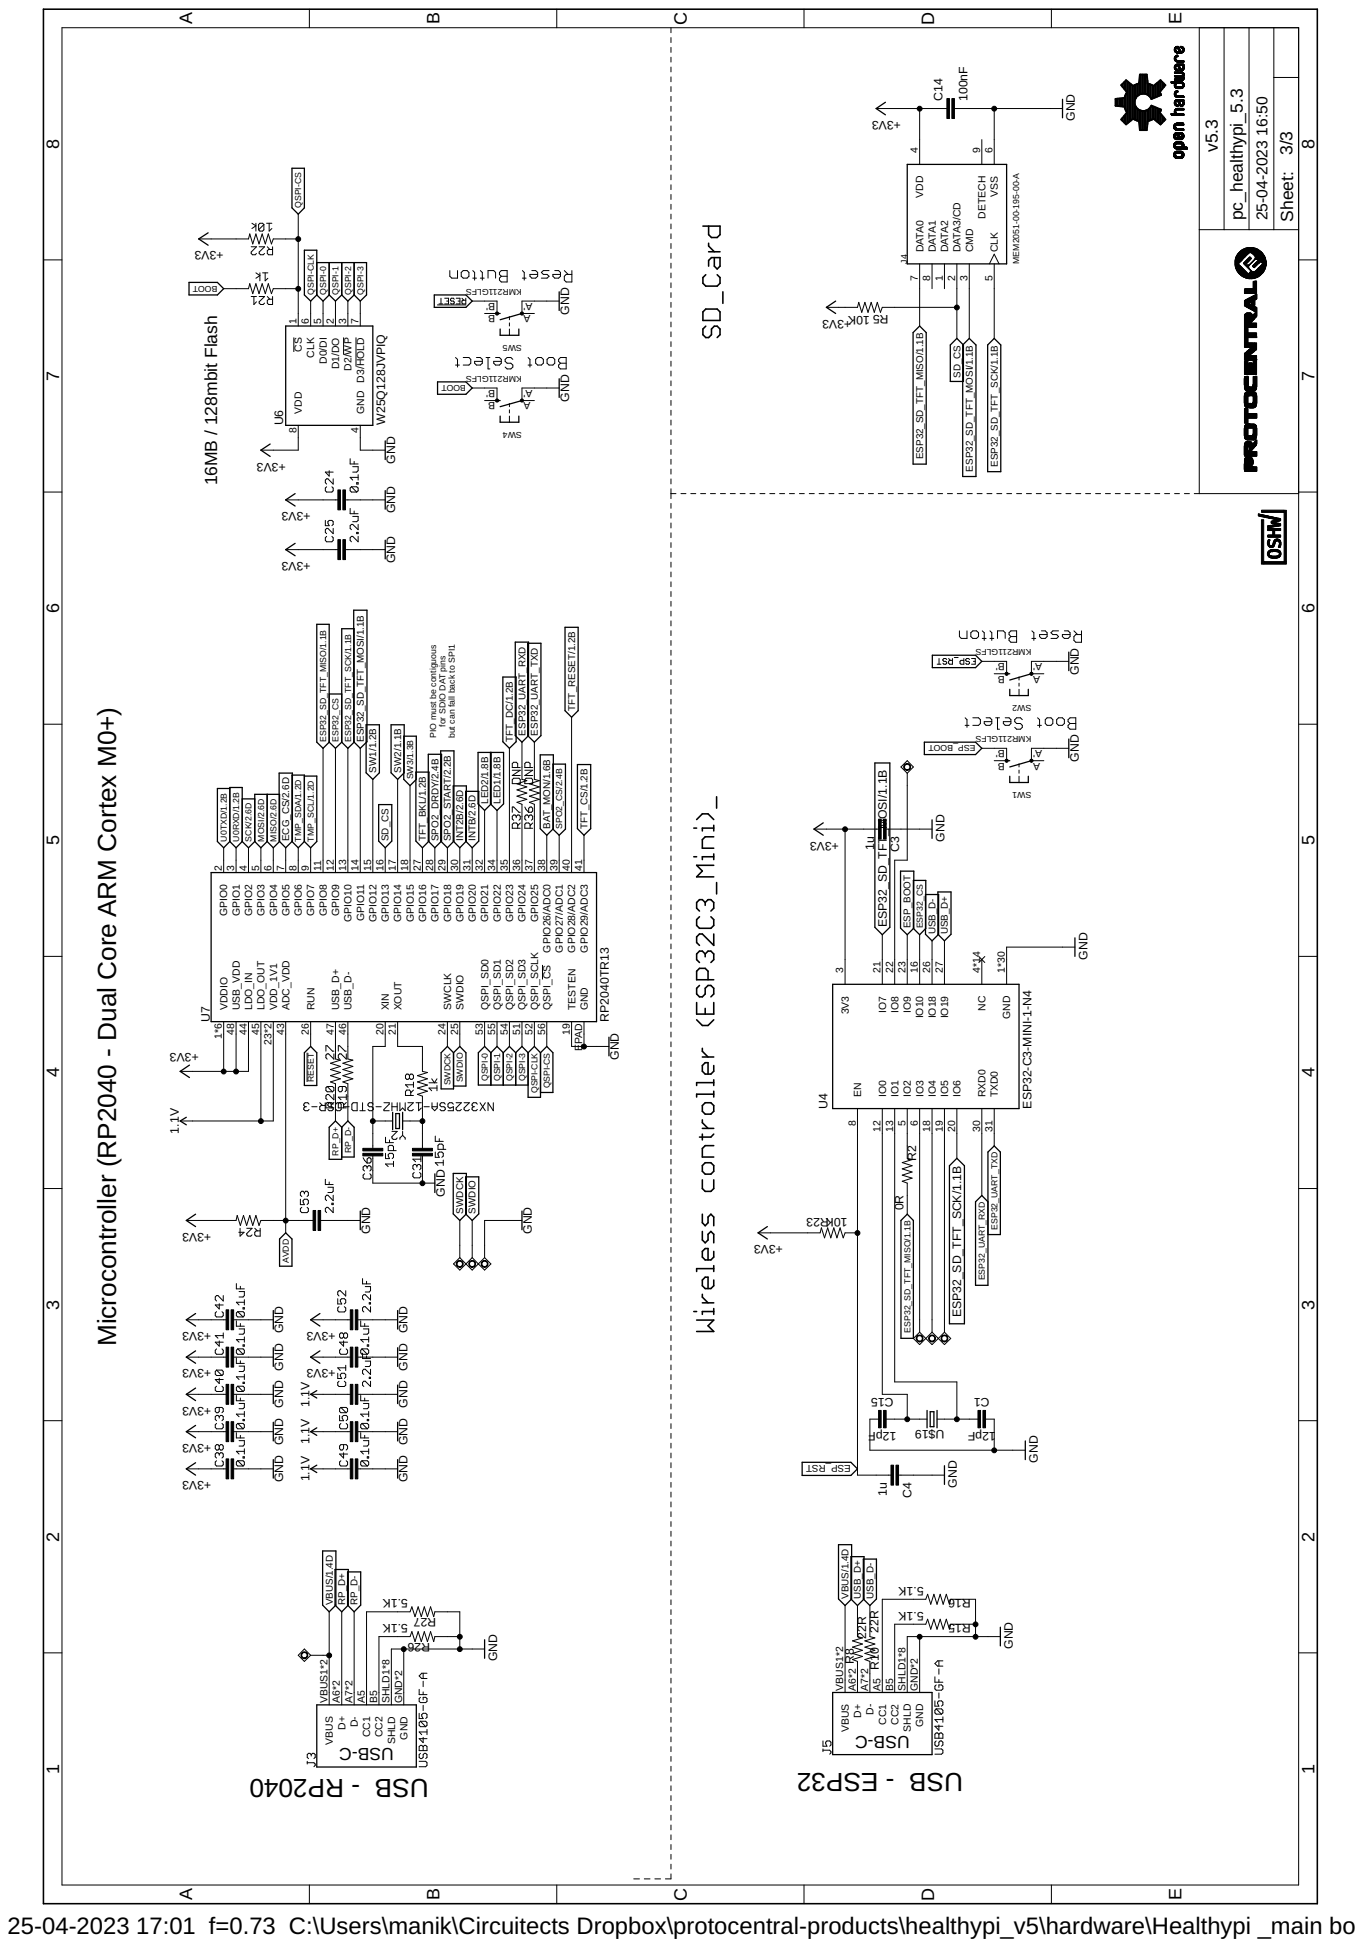
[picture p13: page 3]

PIO must be contiguous

for SDIO DAT pins but can fall back to SPI1 GND

GND GND GND GND GND

25-04-2023 17:01 f=0.73 C:\Users\manik\Circuitects Dropbox\protocentral-products\healthypi_v5\hardware\Healthypi _main board\pc_healthypi_5.3.sch (Sheet: 3/3)

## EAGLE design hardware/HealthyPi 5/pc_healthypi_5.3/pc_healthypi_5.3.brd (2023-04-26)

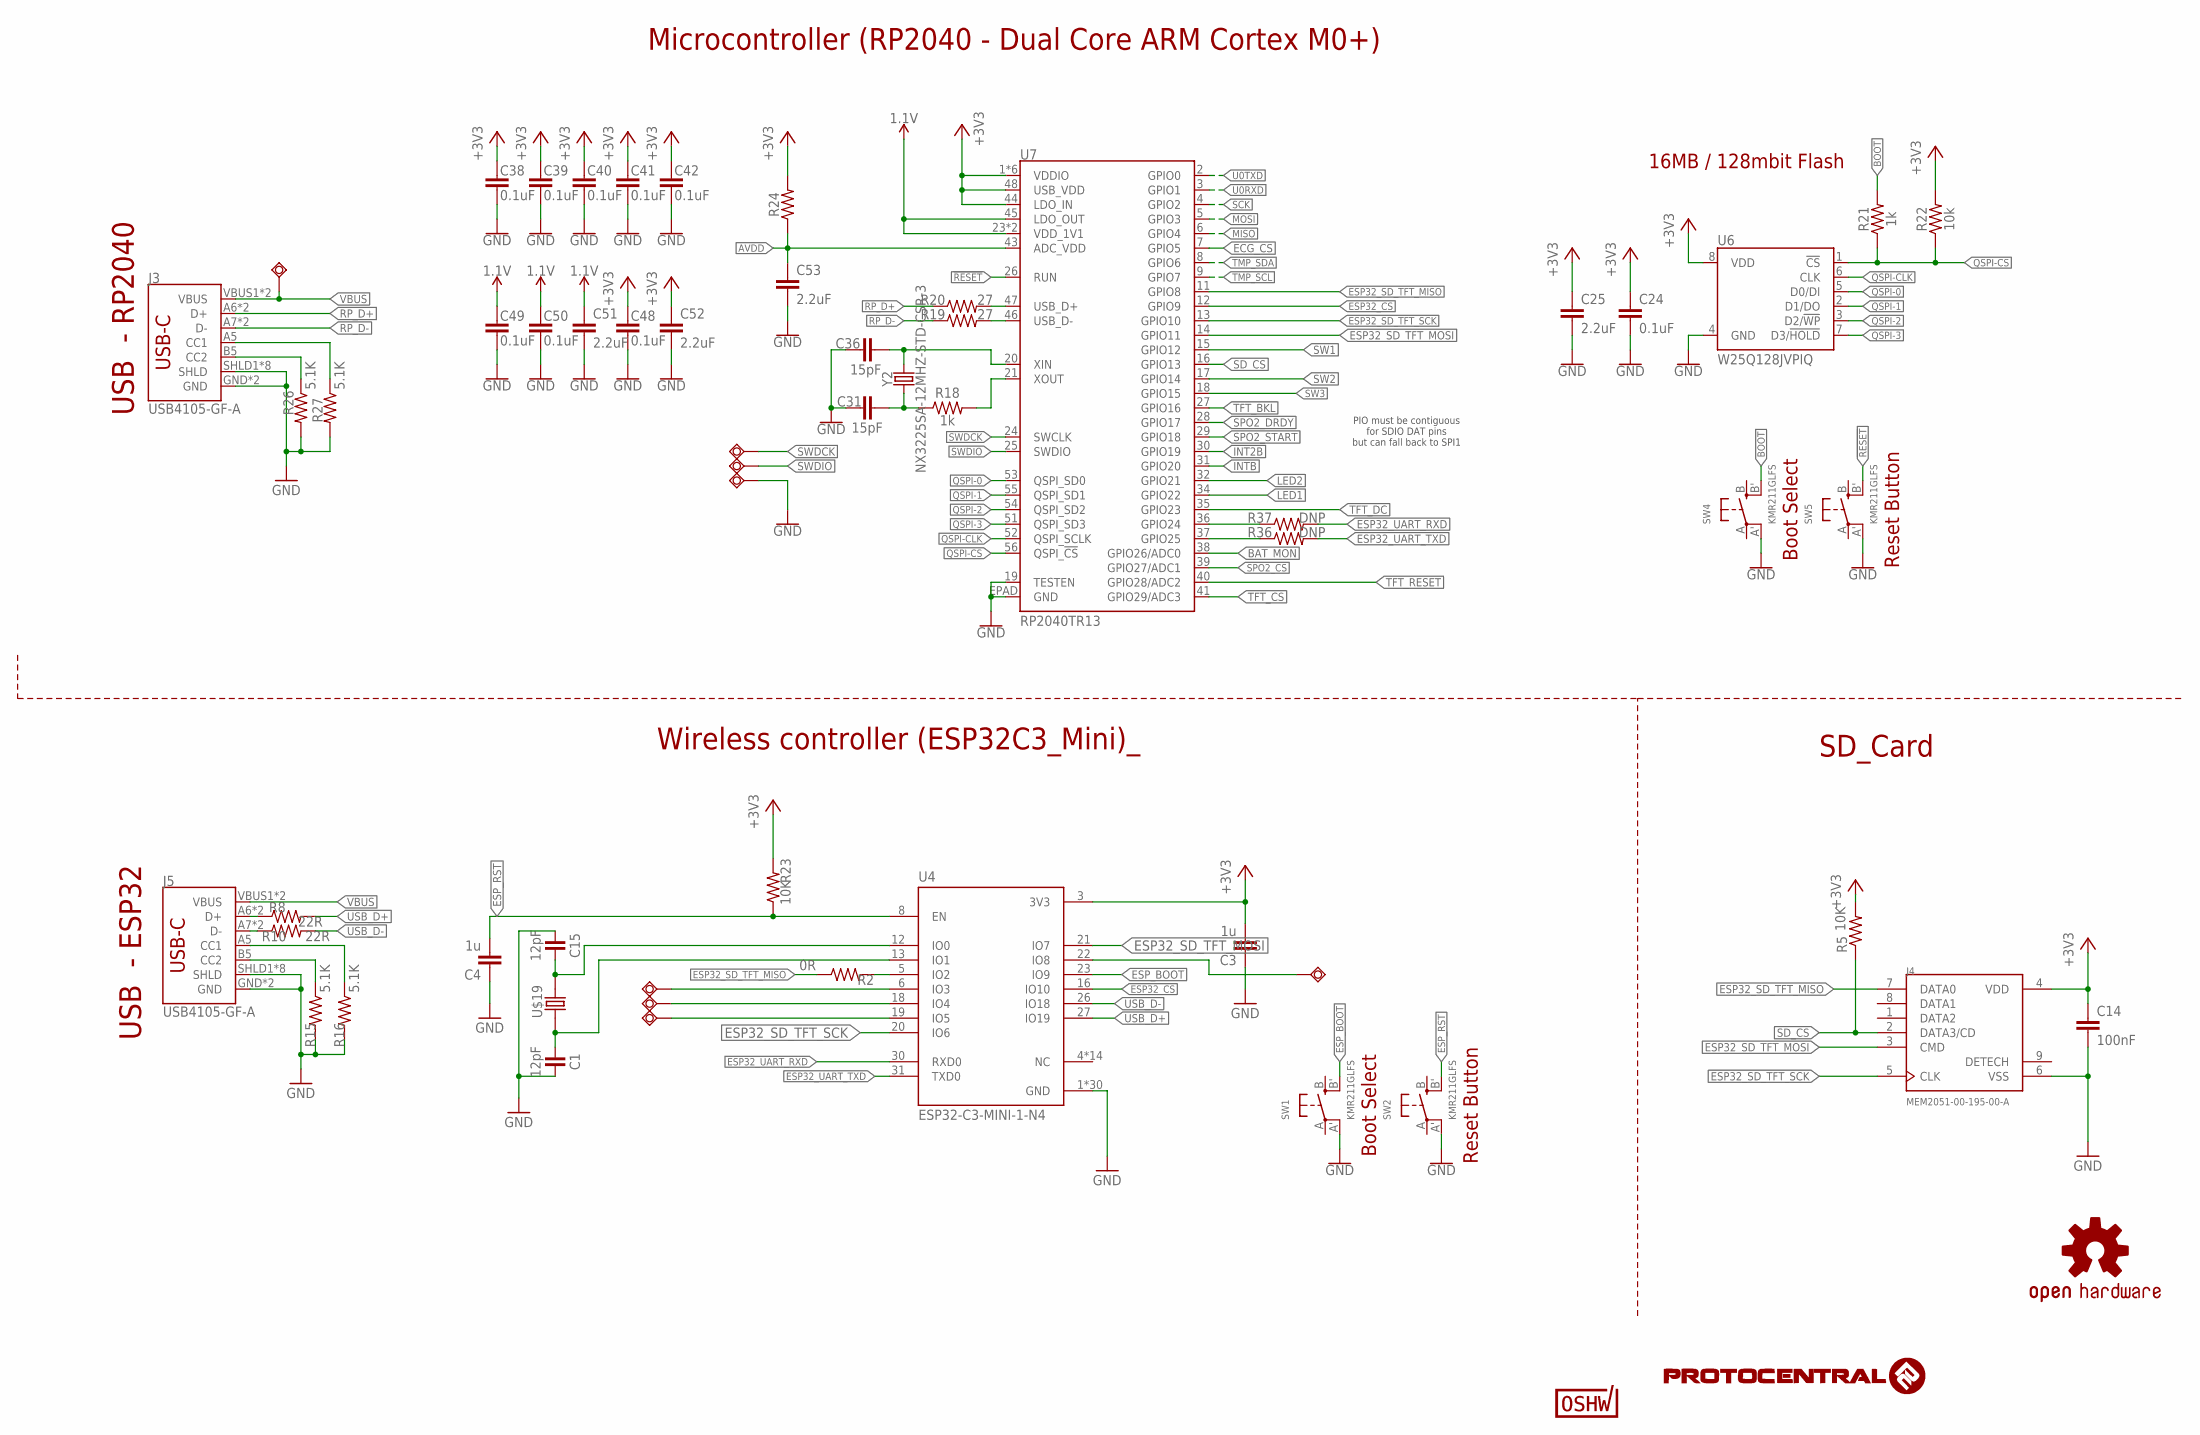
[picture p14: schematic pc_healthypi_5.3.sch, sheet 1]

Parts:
C1, C15: 12pF; C0402
C3, C4: 1u; C0402
C14: 100nF; C0402
C24, C38, C39, C40, C41, C42, C48, C49, C50: 0.1uF; 0402-TIGHT
C25, C51, C52, C53: 2.2uF; 0402-TIGHT
C31, C36: 15pF; 0402-TIGHT
J3, J5: USB4105-GF-A; USB-C-16P
J4: MEM2051-00-195-00-A; GCT_MEM2051-00-195-00-A
R2: 0R; R0402
R5, R23: 10K; R0402
R8, R10: 22R; R0402
R15, R16, R26, R27: 5.1K; R0402
R18, R21: 1k; 0402-TIGHT
R19, R20: 27; 0402-TIGHT
R22: 10k; 0402-TIGHT
R24: 200OHM-0402T-1/16W-1%; 0402-TIGHT
R36, R37: DNP; 0402-TIGHT
SW1, SW2, SW4, SW5: KMR211GLFS; BTN_KMR2_4.6X2.8
SWIO2, SWIO3, SWIO4, SWIO6: TPSQTP11R; TP11R
TP1, TP5, TP6, TP7: TPSQTP11R; TP11R
U4: ESP32-C3-MINI-1-N4; XCVR_ESP32-C3-MINI-1-N4
U6: W25Q128JVPIQ; WSON-8-6X5-SKINNY_CENTERPAD
U7: RP2040TR13; QFN-56
U$19: 520-327-12.5-34B(32.768KHZ); ECX-31B
U$35: OSHW-LOGOM; OSHW-LOGO-M
U$37: CERT-SMALL; CERT-SMALL-SILK
Y2: NX3225SA-12MHZ-STD-CSR-3; CRYSTAL-SMD-2X2.5MM

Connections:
1.1V: C49.1, C50.1, C51.1, U7.23 (VDD_1V1), U7.45 (LDO_OUT), U7.50 (VDD_1V1)
!RESET!: SW5.B' (S1), U7.26 (RUN)
+3V3: C3.2, C14.1, C24.1, C25.1, C38.1, C39.1, C40.1, C41.1, C42.1, C48.1, C52.1, J4.4 (VDD), R5.2, R22.2, R23.2, R24.2, U4.3 (3V3), U6.8 (VDD), U7.1 (VDDIO), U7.10 (VDDIO), U7.22 (VDDIO), U7.33 (VDDIO), U7.42 (VDDIO), U7.44 (LDO_IN), U7.48 (USB_VDD), U7.49 (VDDIO); also elsewhere on the board
AVDD: C53.1, R24.1, U7.43 (ADC_VDD)
BAT_MON: U7.38 (GPIO26/ADC0); also elsewhere on the board
BOOT: R21.2, SW4.B' (S1)
ECG_CS: U7.7 (GPIO5); also elsewhere on the board
ESP32_CS: U4.16 (IO10), U7.12 (GPIO9)
ESP32_MISO: R2.2, U4.5 (IO2)
ESP32_SD_TFT_MISO: J4.7 (DATA0), R2.1, U7.11 (GPIO8); also elsewhere on the board
ESP32_SD_TFT_MOSI: J4.3 (CMD), U4.21 (IO7), U7.14 (GPIO11); also elsewhere on the board
ESP32_SD_TFT_SCK: J4.5 (CLK), U4.20 (IO6), U7.13 (GPIO10); also elsewhere on the board
ESP32_UART_RXD: R37.2, U4.30 (RXD0)
ESP32_UART_TXD: R36.2, U4.31 (TXD0)
ESP_BOOT: SW1.B' (S1), U4.23 (IO9)
ESP_RST: C4.2, R23.1, SW2.B' (S1), U4.8 (EN)
GND: C1.2, C3.1, C4.1, C14.2, C15.1, C24.2, C25.2, C31.1, C36.1, C38.2, C39.2, C40.2, C41.2, C42.2, C48.2, C49.2, C50.2, C51.2, C52.2, C53.2, J3.GND, J3.GND2 (GND), J3.SHLD1 (SHLD), J3.SHLD2 (SHLD), J3.SHLD3 (SHLD), J3.SHLD4 (SHLD), J3.SHLD5 (SHLD), J3.SHLD6 (SHLD), J3.SHLD7 (SHLD), J3.SHLD8 (SHLD), J4.6 (VSS), J5.GND, J5.GND2 (GND), J5.SHLD1 (SHLD), J5.SHLD2 (SHLD), J5.SHLD3 (SHLD), J5.SHLD4 (SHLD), J5.SHLD5 (SHLD), J5.SHLD6 (SHLD), J5.SHLD7 (SHLD), J5.SHLD8 (SHLD), R15.2, R16.2, R26.2, R27.2, SW1.A' (P1), SW2.A' (P1), SW4.A' (P1), SW5.A' (P1), TP1.TP, U4.1 (GND), U4.2 (GND), U4.11 (GND), U4.14 (GND), U4.36 (GND), U4.37 (GND), U4.38 (GND), U4.39 (GND), U4.40 (GND), U4.41 (GND), U4.42 (GND), U4.43 (GND), U4.44 (GND), U4.45 (GND), U4.46 (GND), U4.47 (GND), U4.48 (GND), U4.49_1 (GND), U4.49_2 (GND), U4.49_3 (GND), U4.49_4 (GND), U4.49_5 (GND), U4.49_6 (GND), U4.49_7 (GND), U4.49_8 (GND), U4.49_9 (GND), U4.50 (GND), U4.51 (GND), U4.52 (GND), U4.53 (GND), U6.4 (GND), U7.19 (TESTEN), U7.EPAD (GND); also elsewhere on the board
INT2B: U7.30 (GPIO19); also elsewhere on the board
INTB: U7.31 (GPIO20); also elsewhere on the board
LED1: U7.34 (GPIO22); also elsewhere on the board
LED2: U7.32 (GPIO21); also elsewhere on the board
MISO: U7.6 (GPIO4); also elsewhere on the board
MOSI: U7.5 (GPIO3); also elsewhere on the board
unnamed: J5.B5 (CC2), R15.1
unnamed: J5.A5 (CC1), R16.1
unnamed: SWIO3.TP, U4.6 (IO3)
unnamed: J5.A6 (D+), J5.B6 (D+), R8.1
unnamed: R18.2, U7.21 (XOUT)
unnamed: J5.A7 (D-), J5.B7 (D-), R10.1
unnamed: C36.2, U7.20 (XIN), Y2.P3 (2)
unnamed: C31.2, R18.1, Y2.P1 (1)
unnamed: J3.B5 (CC2), R26.1
unnamed: SWIO4.TP, U4.18 (IO4)
unnamed: C15.2, U4.12 (IO0), U$19.P$2 (2)
unnamed: J3.A5 (CC1), R27.1
unnamed: C1.1, U4.13 (IO1), U$19.P$1 (1)
unnamed: R37.1, U7.36 (GPIO24)
unnamed: R36.1, U7.37 (GPIO25)
unnamed: SWIO6.TP, U4.19 (IO5)
unnamed: SWIO2.TP, U4.22 (IO8)
QSPI-0: U6.5 (D0/DI), U7.53 (QSPI_SD0)
QSPI-1: U6.2 (D1/DO), U7.55 (QSPI_SD1)
QSPI-2: U6.3 (D2/!WP!), U7.54 (QSPI_SD2)
QSPI-3: U6.7 (D3/!HOLD!), U7.51 (QSPI_SD3)
QSPI-CLK: U6.6 (CLK), U7.52 (QSPI_SCLK)
QSPI-CS: R21.1, R22.1, U6.1 (!CS!), U7.56 (QSPI_!CS!)
RP_D+: J3.A6 (D+), J3.B6 (D+), R20.1
RP_D-: J3.A7 (D-), J3.B7 (D-), R19.1
SCK: U7.4 (GPIO2); also elsewhere on the board
SD_CS: J4.2 (DATA3/CD), R5.1, U7.16 (GPIO13)
SPO2_CS: U7.39 (GPIO27/ADC1); also elsewhere on the board
SPO2_DRDY: U7.28 (GPIO17); also elsewhere on the board
SPO2_START: U7.29 (GPIO18); also elsewhere on the board
SW1: U7.15 (GPIO12); also elsewhere on the board
SW2: U7.17 (GPIO14); also elsewhere on the board
SW3: U7.18 (GPIO15); also elsewhere on the board
SWDCK: TP6.TP, U7.24 (SWCLK)
SWDIO: TP7.TP, U7.25 (SWDIO)
TFT_BKL: U7.27 (GPIO16); also elsewhere on the board
TFT_CS: U7.41 (GPIO29/ADC3); also elsewhere on the board
TFT_DC: U7.35 (GPIO23); also elsewhere on the board
TFT_RESET: U7.40 (GPIO28/ADC2); also elsewhere on the board
TMP_SCL: U7.9 (GPIO7); also elsewhere on the board
TMP_SDA: U7.8 (GPIO6); also elsewhere on the board
U0RXD: U7.3 (GPIO1); also elsewhere on the board
U0TXD: U7.2 (GPIO0); also elsewhere on the board
USB_D+: R8.2, U4.27 (IO19)
USB_D-: R10.2, U4.26 (IO18)
USB_F_N: R19.2, U7.46 (USB_D-)
USB_F_P: R20.2, U7.47 (USB_D+)
VBUS: J3.VBUS1 (VBUS), J3.VBUS2 (VBUS), J5.VBUS1 (VBUS), J5.VBUS2 (VBUS), TP5.TP; also elsewhere on the board

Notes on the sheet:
Reset Button
Microcontroller (RP2040 - Dual Core ARM Cortex M0+)
PIO must be contiguous for SDIO DAT pins but can fall back to SPI1
Boot Select
16MB / 128mbit Flash
USB - RP2040
Wireless controller (ESP32C3_Mini)_
SD_Card
USB - ESP32

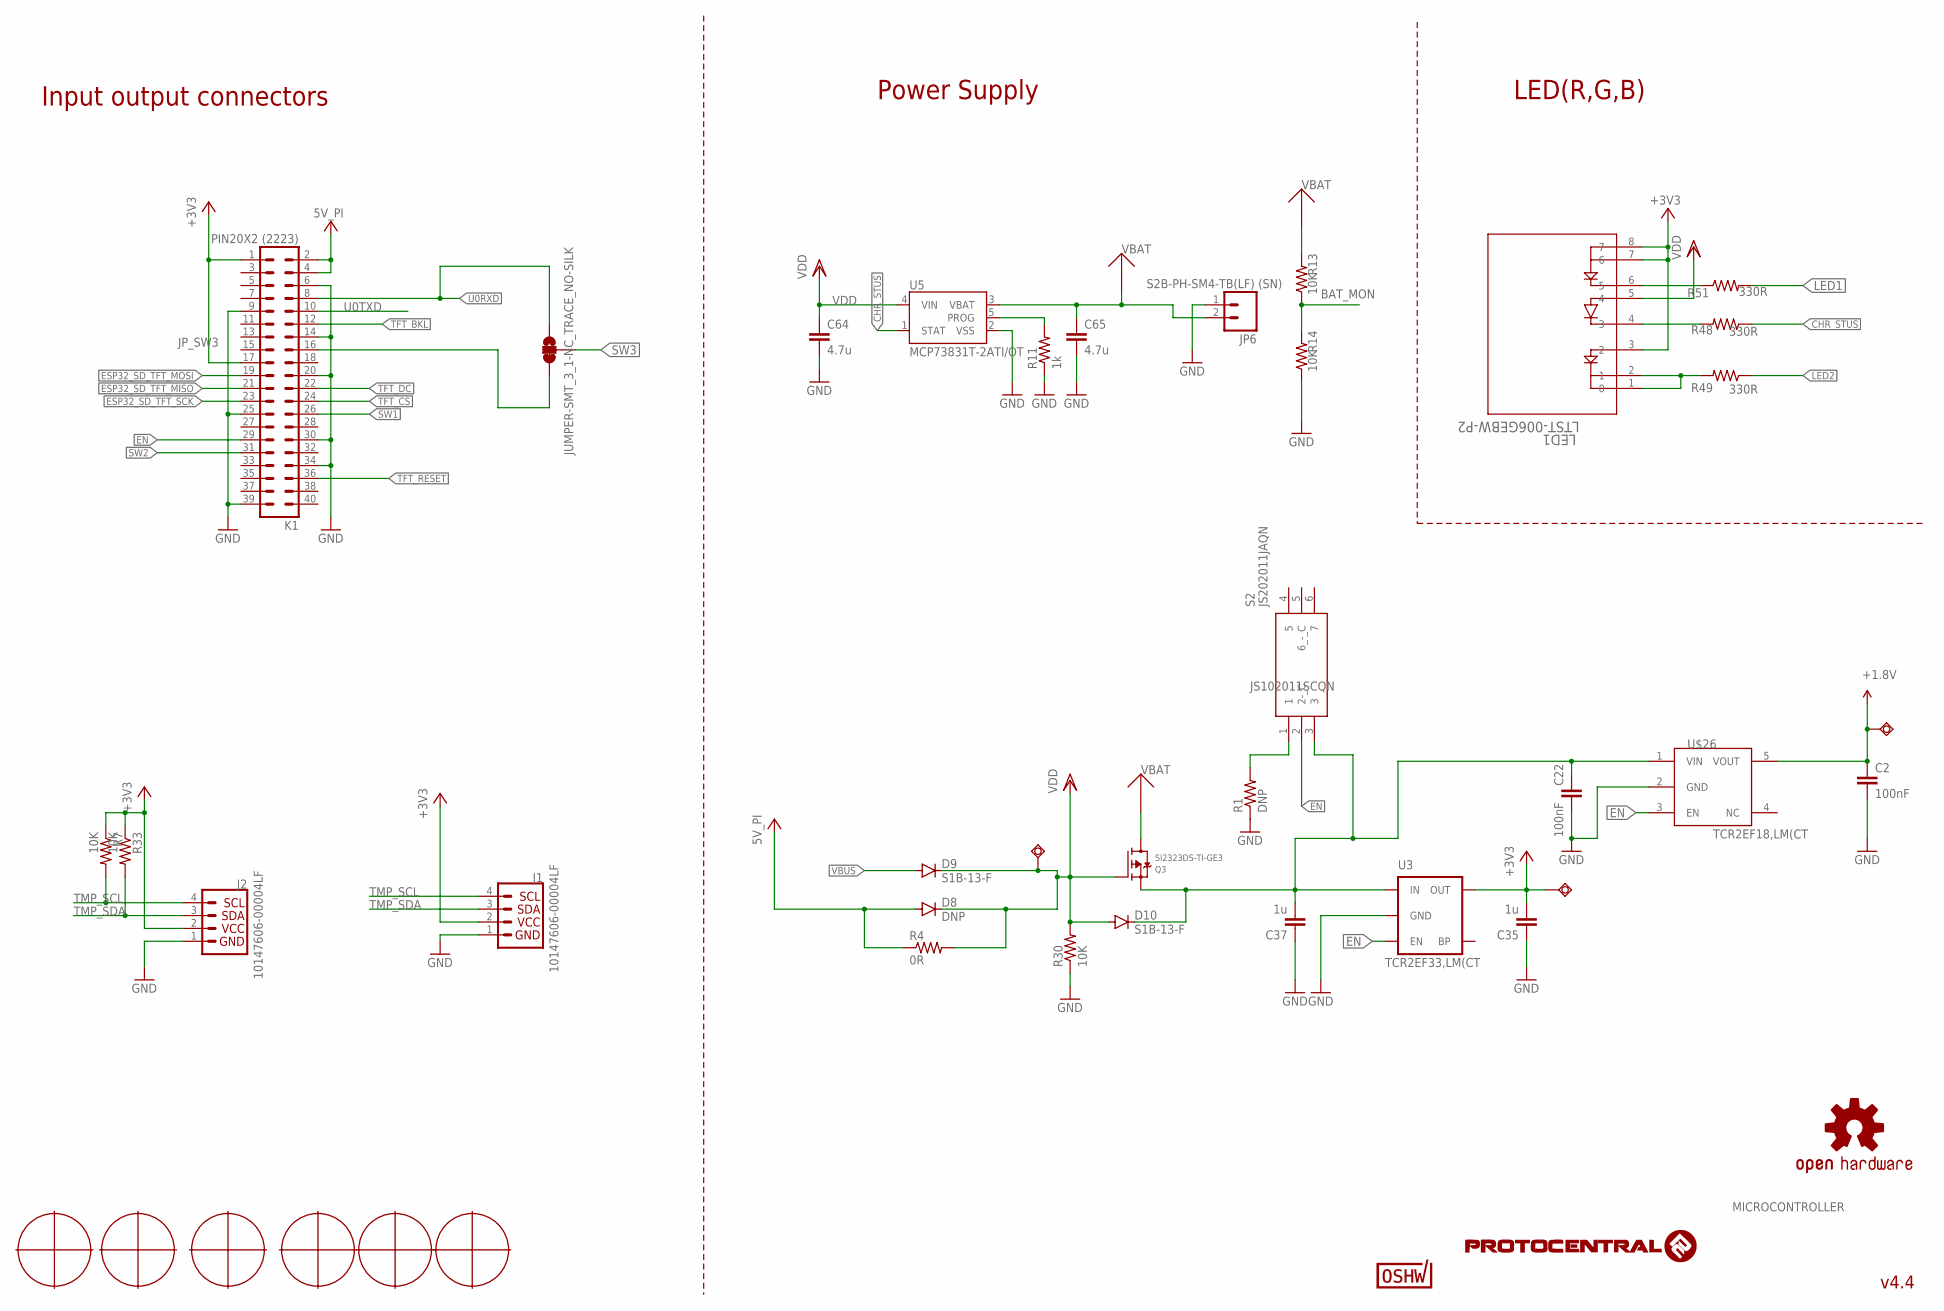
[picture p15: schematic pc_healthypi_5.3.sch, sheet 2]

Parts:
C2, C22: 100nF; C0402
C35, C37: 1u; C0402
C64, C65: 4.7u; C0805
D8: DNP; SOD-123_MINI-SMA
D9, D10: S1B-13-F; SOD-123_MINI-SMA
J1, J2: 10147606-00004LF; JST04_1MM_RA
JP6: S2B-PH-SM4-TB(LF) (SN); JST-2-SMD
JP_SW3: JUMPER-SMT_3_1-NC_TRACE_NO-SILK; SMT-JUMPER_3_1-NC_TRACE_NO-SILK
K1: PIN20X2 (2223); PIN_20X2
LED1: LTST-006GEBW-P2; LTST-008BGEW_LTO
Q3: SI2323DS-TI-GE3; SOT23-R
R1: DNP; R0402
R4: 0R; 0805
R7, R13, R14, R30, R33: 10K; R0402
R11: 1k; R0402
R48, R49, R51: 330R; 0402-RES
S2: JS202011JAQN
SWIO1, SWIO5, SWIO7: TPSQTP11R; TP11R
U3: TCR2EF33,LM(CT; SOT23-5
U5: MCP73831T-2ATI/OT; SOT23-5
U$1, U$21, U$23, U$25, U$28, U$29: FUDCIALPOINTS; FIDUCIALPOINTS
U$5: OSHW-LOGOM; OSHW-LOGO-M
U$13: CERT-SMALL; CERT-SMALL-SILK
U$26: TCR2EF18,LM(CT; SOT95P285X140-5N

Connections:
+1.8V: C2.1, SWIO5.TP, U$26.5 (VOUT); also elsewhere on the board
+3V3: C35.2, J1.2, J2.2, K1.1, K1.17, LED1.3 (2), LED1.7 (6), LED1.8 (7), R7.1, R33.1, SWIO1.TP, U3.5 (OUT); also elsewhere on the board
+5V: D8.A, K1.2, K1.4, R4.1
BAT_MON: R13.1, R14.2; also elsewhere on the board
CHR_STUS: R48.1, U5.1 (STAT)
EN: K1.29, S2.2 (2-_C), U3.3 (EN), U$26.3 (EN)
ESP32_SD_TFT_MISO: K1.21; also elsewhere on the board
ESP32_SD_TFT_MOSI: K1.19; also elsewhere on the board
ESP32_SD_TFT_SCK: K1.23; also elsewhere on the board
GND: C2.2, C22.2, C35.1, C37.1, C64.2, C65.2, J1.1, J2.1, JP6.1, K1.6, K1.9, K1.14, K1.20, K1.25, K1.30, K1.34, K1.39, R1.1, R11.1, R14.1, R30.1, U3.2 (GND), U5.2 (VSS), U$26.2 (GND); also elsewhere on the board
LED1: R51.2; also elsewhere on the board
LED2: R49.1; also elsewhere on the board
unnamed: R1.2, S2.1
unnamed: LED1.4 (3), R48.2
unnamed: JP_SW3.3, K1.16
unnamed: C22.1, C37.2, D10.C, Q3.2 (S), S2.3, U3.1 (IN), U$26.1 (VIN)
unnamed: R11.2, U5.5 (PROG)
unnamed: LED1.1 (0), LED1.2 (1), R49.2
unnamed: LED1.6 (5), R51.1
SW1: K1.26; also elsewhere on the board
SW2: K1.31; also elsewhere on the board
SW3: JP_SW3.2; also elsewhere on the board
TFT_BKL: K1.12; also elsewhere on the board
TFT_CS: K1.24; also elsewhere on the board
TFT_DC: K1.22; also elsewhere on the board
TFT_RESET: K1.36; also elsewhere on the board
TMP_SCL: J1.4, J2.4, R7.2; also elsewhere on the board
TMP_SDA: J1.3, J2.3, R33.2; also elsewhere on the board
U0RXD: JP_SW3.1, K1.8; also elsewhere on the board
U0TXD: K1.10; also elsewhere on the board
VBAT: C65.1, JP6.2, Q3.3 (D), R13.2, U5.3 (VBAT)
VBUS: D9.A; also elsewhere on the board
VDD: C64.1, D8.C, D9.C, D10.A, LED1.5 (4), Q3.1 (G), R4.2, R30.2, SWIO7.TP, U5.4 (VIN)

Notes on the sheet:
v4.4
MICROCONTROLLER
JS102011SCQN
Input output connectors
Power Supply
LED(R,G,B)

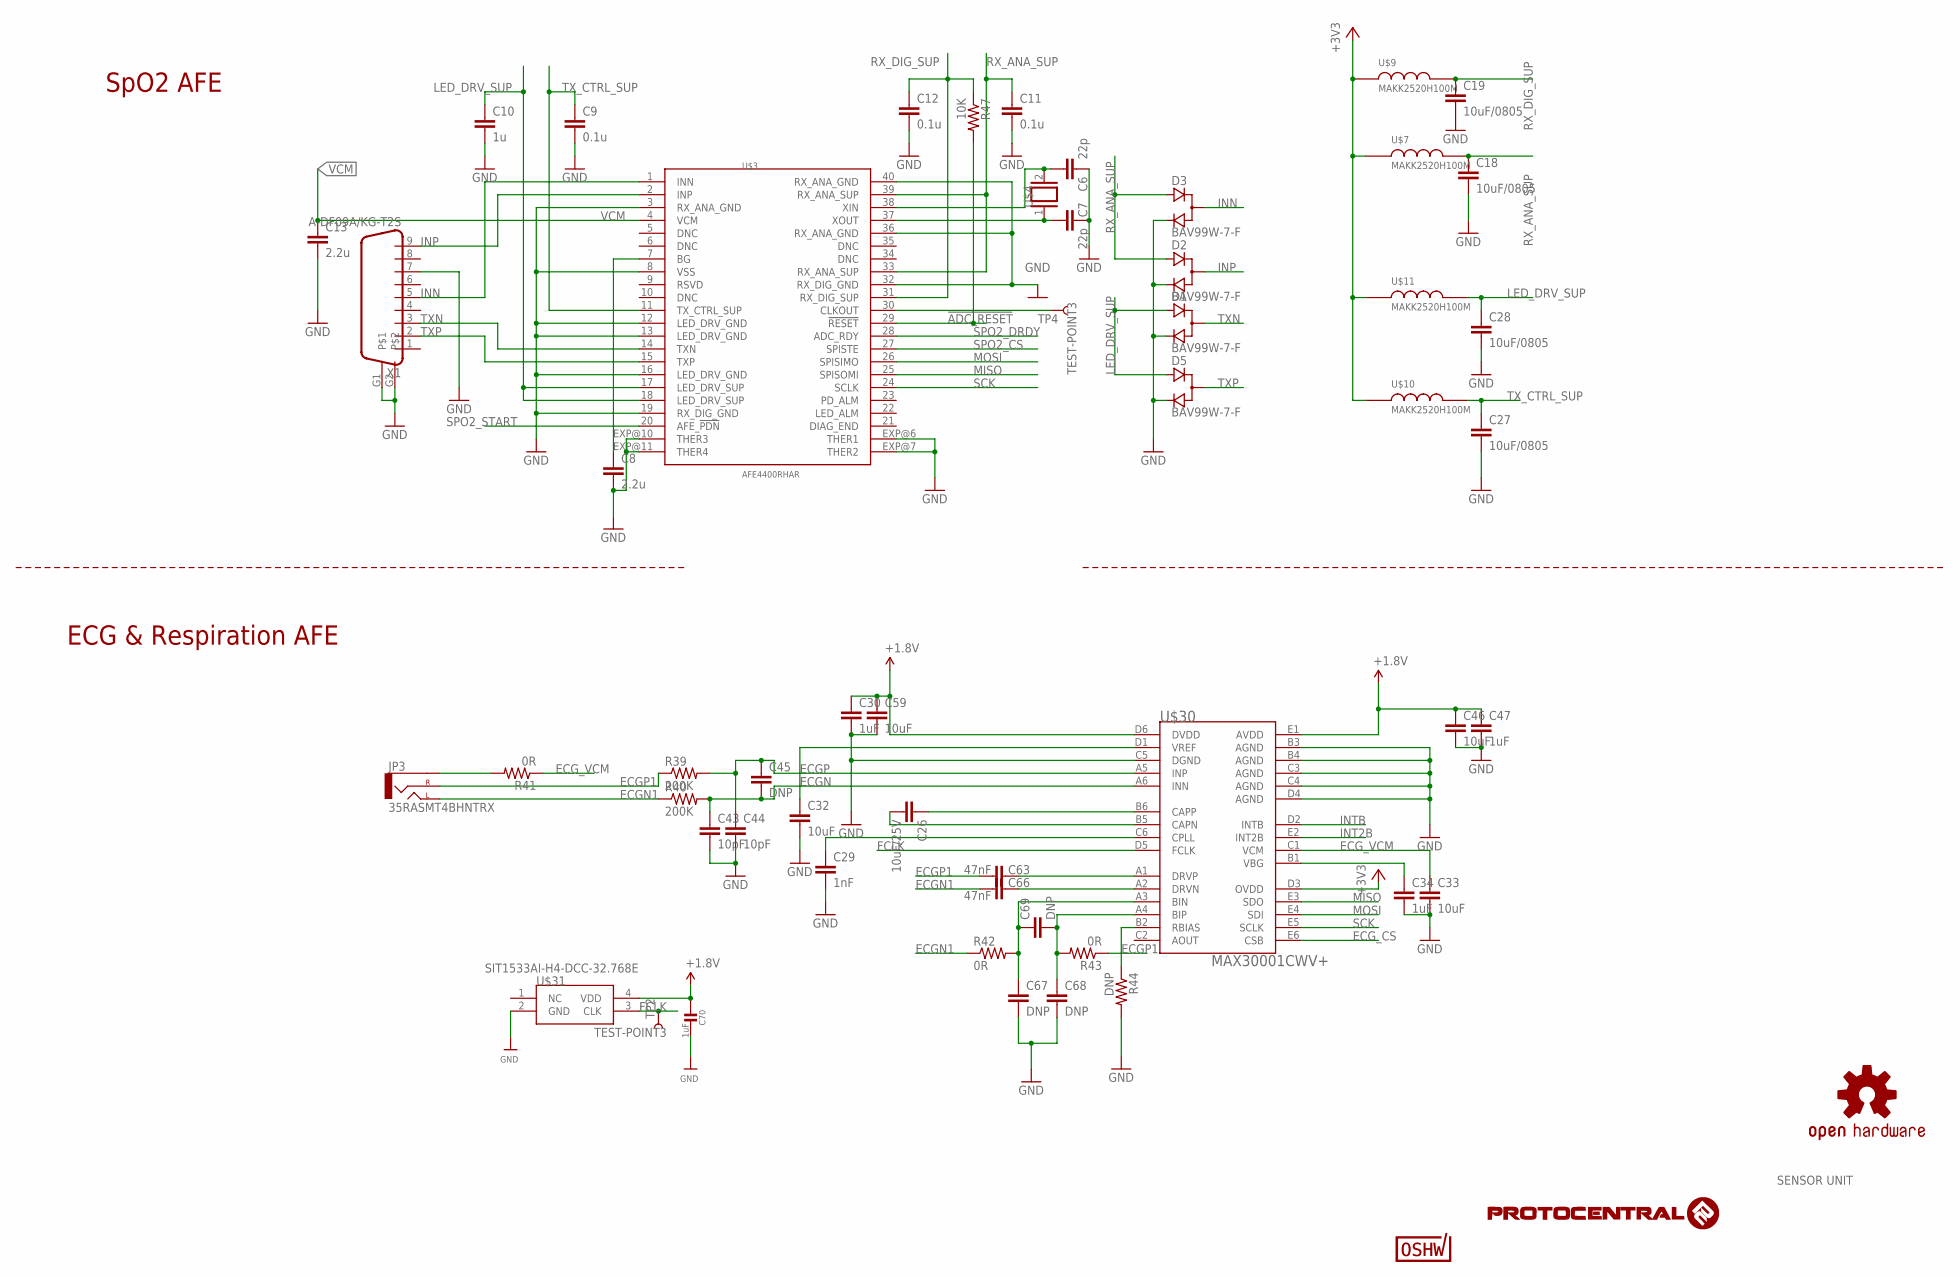
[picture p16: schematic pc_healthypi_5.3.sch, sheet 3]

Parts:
C6, C7: 22p; C0402
C8, C13: 2.2u; C0402
C9, C11, C12: 0.1u; C0402
C10: 1u; C0805
C18, C19, C27, C28: 10uF/0805; C0805
C26: 10uF/25V; C0805
C29: 1nF; C0402
C30, C34, C47: 1uF; C0402
C32, C33, C46, C59: 10uF; C0805
C43, C44: 10pF; C0402
C45, C67, C68, C69: DNP; C0402
C63, C66: 47nF; C0402
C70: 1uF; 0402
D1, D2, D3, D5: BAV99W-7-F; SOT323
JP3: 35RASMT4BHNTRX; AUDIO-JACK-3.5MM-SMD
R39, R40: 200K; 0805
R41: 0R; 0805
R42, R43: 0R; 0402-RES
R44: DNP; 0402-RES
R47: 10K; R0402
TP2, TP4: TEST-POINT3; PAD.03X.03
U$3: AFE4400RHAR; QFN-40
U$4: ABM3-8.000MHZ-B4Y-T; XTAL_HC49P488W43L1150T466H350
U$7, U$9, U$10, U$11: MAKK2520H100M; LPS
U$24: OSHW-LOGOM; OSHW-LOGO-M
U$30: MAX30001CWV+; 30WLP
U$31: SIT1533AI-H4-DCC-32.768E; SIT1533
U$36: CERT-SMALL; CERT-SMALL-SILK
X1: A-DF09A/KG-T2S; DB9

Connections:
!ADC_RESET: R47.2, U$3.29 (!RESET)
+1.8V: C30.1, C46.1, C47.1, C59.1, C70.1, U$30.D6 (DVDD), U$30.E1 (AVDD), U$31.4 (VDD); also elsewhere on the board
+3V3: U$7.1, U$9.1, U$10.1, U$11.1, U$30.D3 (OVDD); also elsewhere on the board
ECGN: C43.1, C45.2, R40.2, U$30.A6 (INN)
ECGN1: C66.1, JP3.TIP (LEFT), R40.1, R42.1
ECGP: C44.1, C45.1, R39.2, U$30.A5 (INP)
ECGP1: C63.1, JP3.RING (RIGHT), R39.1, R43.1
ECG_CS: U$30.E6 (CSB); also elsewhere on the board
ECG_VCM: C33.1, R41.1, U$30.C1 (VCM)
FCLK: TP2.P$1, U$30.D5 (FCLK), U$31.3 (CLK)
GND: C6.1, C7.1, C8.2, C9.2, C10.2, C11.2, C12.2, C13.2, C18.2, C19.2, C27.2, C28.2, C29.2, C30.2, C32.2, C33.2, C34.2, C43.2, C44.2, C46.2, C47.2, C59.2, C67.2, C68.2, C70.2, D1.2 (C), D2.2 (C), D3.2 (C), D5.2 (C), R44.2, U$3.3 (RX_ANA_GND), U$3.8 (VSS), U$3.12 (LED_DRV_GND), U$3.13 (LED_DRV_GND), U$3.16 (LED_DRV_GND), U$3.19 (RX_DIG_GND), U$3.32 (RX_DIG_GND), U$3.36 (RX_ANA_GND), U$3.40 (RX_ANA_GND), U$3.EXP@6 (THER1), U$3.EXP@7 (THER2), U$3.EXP@10 (THER3), U$3.EXP@11 (THER4), U$30.B3 (AGND), U$30.B4 (AGND), U$30.C3 (AGND), U$30.C4 (AGND), U$30.C5 (DGND), U$30.D4 (AGND), U$31.2 (GND), X1.7, X1.G1, X1.G2; also elsewhere on the board
INN: D3.1 (CA), U$3.1 (INN), X1.5
INP: D2.1 (CA), U$3.2 (INP), X1.9
INT2B: U$30.E2 (INT2B); also elsewhere on the board
INTB: U$30.D2 (INTB); also elsewhere on the board
LED_DRV_SUP: C10.1, C28.1, D1.3 (A), D5.3 (A), U$3.17 (LED_DRV_SUP), U$3.18 (LED_DRV_SUP), U$11.2
MISO: U$3.25 (SPISOMI), U$30.E3 (SDO); also elsewhere on the board
MOSI: U$3.26 (SPISIMO), U$30.E4 (SDI); also elsewhere on the board
unnamed: C6.2, U$3.38 (XIN), U$4.2
unnamed: C7.2, U$3.37 (XOUT), U$4.1
unnamed: C8.1, U$3.7 (BG)
unnamed: TP4.P$1, U$3.30 (CLKOUT)
unnamed: C29.1, U$30.C6 (CPLL)
unnamed: C26.2, U$30.B5 (CAPN)
unnamed: C32.1, U$30.D1 (VREF)
unnamed: C34.1, U$30.B1 (VBG)
unnamed: JP3.SLEEVE, R41.2
unnamed: C26.1, U$30.B6 (CAPP)
unnamed: C63.2, U$30.A1 (DRVP)
unnamed: C66.2, U$30.A2 (DRVN)
unnamed: C67.1, C69.1, R42.2, U$30.A3 (BIN)
unnamed: C68.1, C69.2, R43.2, U$30.A4 (BIP)
unnamed: R44.1, U$30.B2 (RBIAS)
RX_ANA_SUP: C11.1, C18.1, D2.3 (A), D3.3 (A), U$3.33 (RX_ANA_SUP), U$3.39 (RX_ANA_SUP), U$7.2
RX_DIG_SUP: C12.1, C19.1, R47.1, U$3.31 (RX_DIG_SUP), U$9.2
SCK: U$3.24 (SCLK), U$30.E5 (SCLK); also elsewhere on the board
SPO2_CS: U$3.27 (SPISTE); also elsewhere on the board
SPO2_DRDY: U$3.28 (ADC_RDY); also elsewhere on the board
SPO2_START: U$3.20 (AFE_!PDN); also elsewhere on the board
TXN: D1.1 (CA), U$3.14 (TXN), X1.3
TXP: D5.1 (CA), U$3.15 (TXP), X1.2
TX_CTRL_SUP: C9.1, C27.1, U$3.11 (TX_CTRL_SUP), U$10.2
VCM: C13.1, U$3.4 (VCM)

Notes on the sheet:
SENSOR UNIT
SpO2 AFE
ECG & Respiration AFE

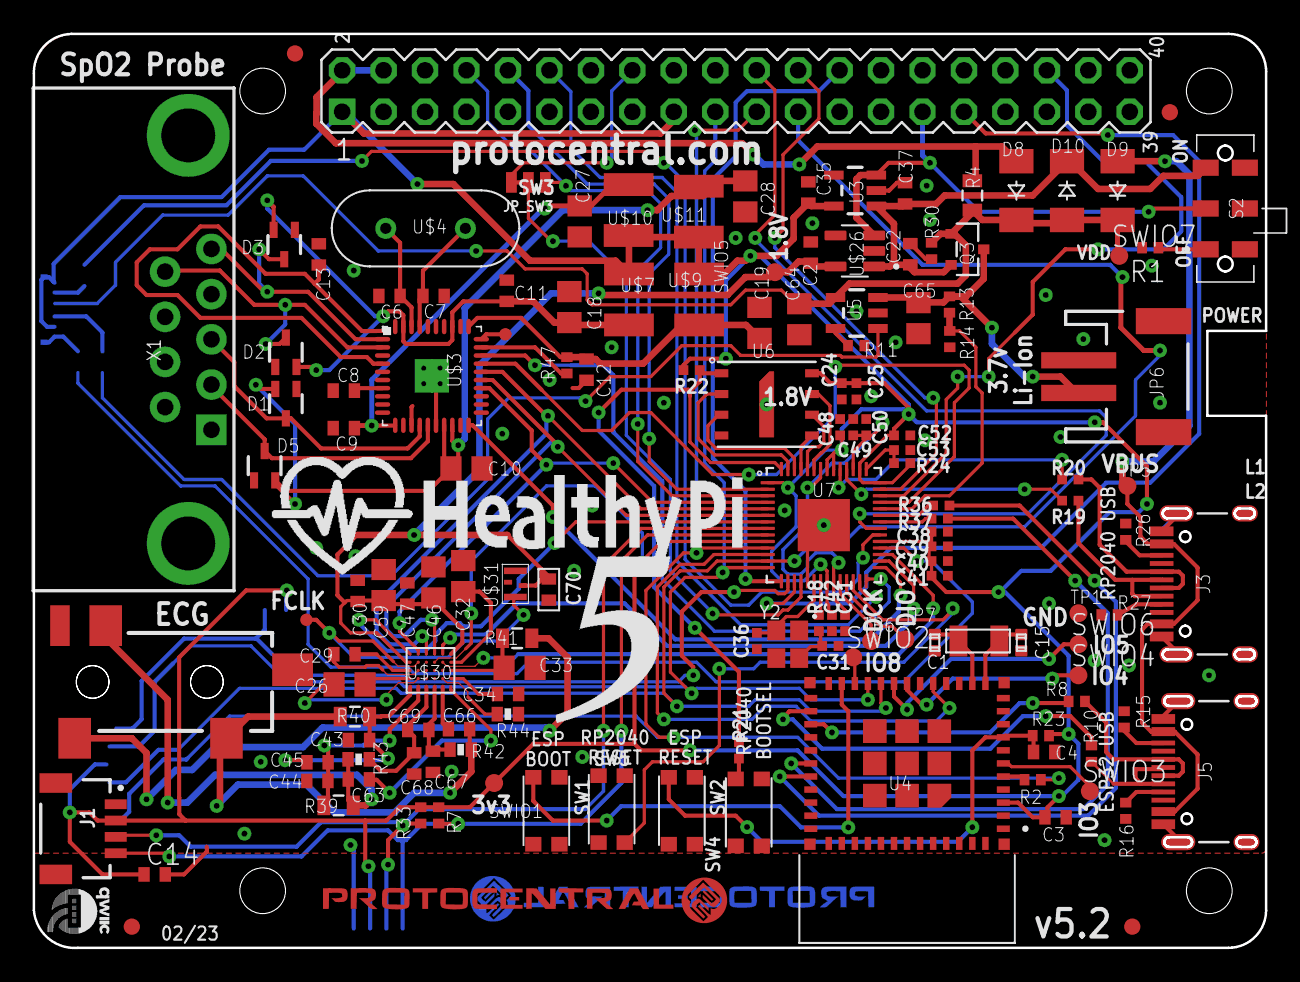
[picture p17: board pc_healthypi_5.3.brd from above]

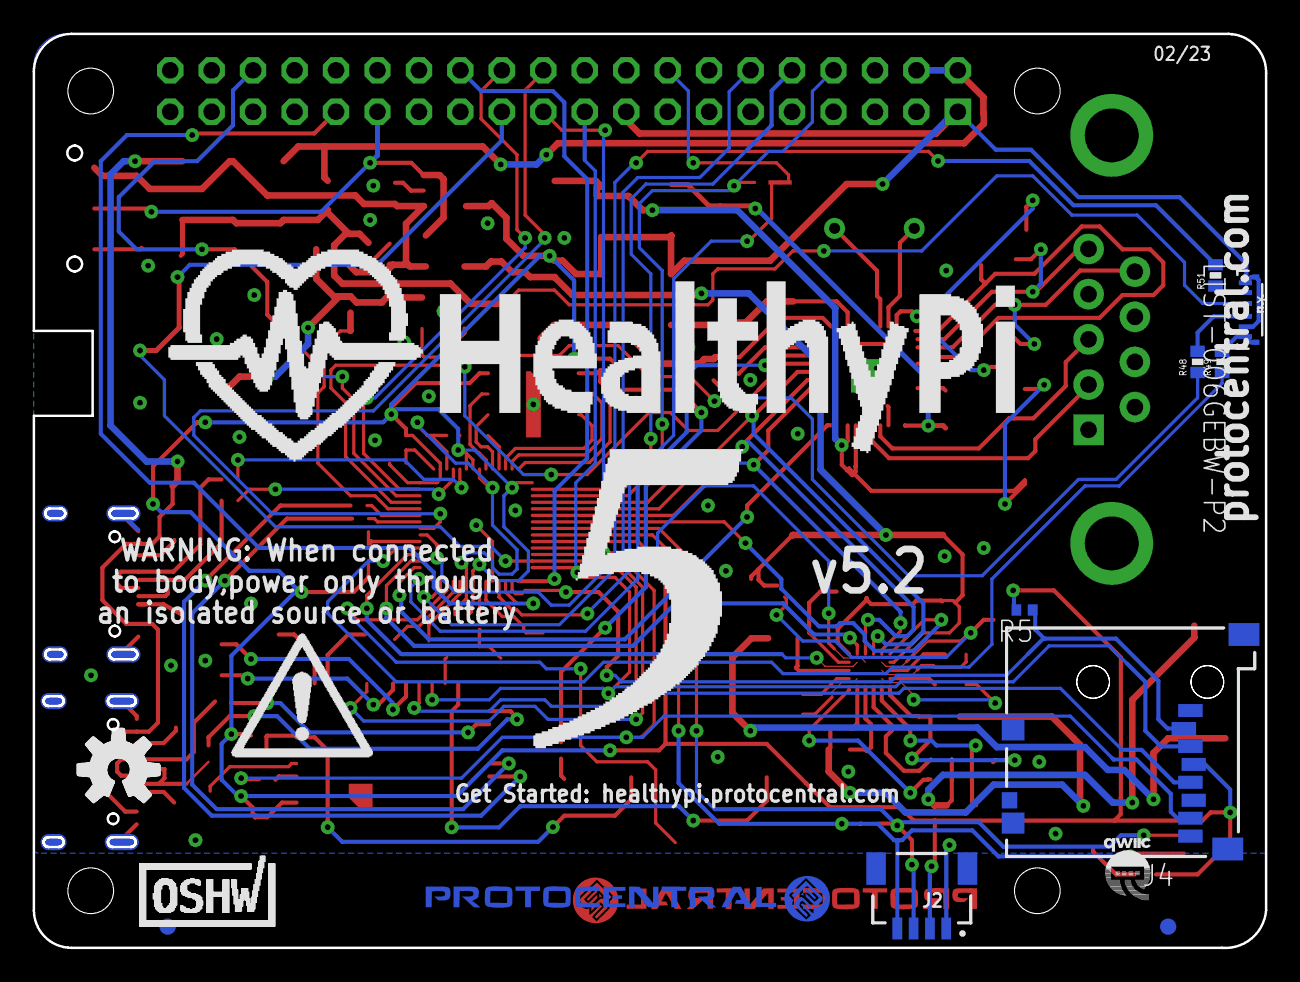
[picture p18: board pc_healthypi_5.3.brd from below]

Board: 2 copper layers, 75.5 x 56.0 mm, 164 parts (19 on the bottom side), 115 nets.

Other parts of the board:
U$2: HEALTHYPI_5_ONLY
U$15, U$59: QWIIC#LABEL#FULL#M#PNG
U$17: WARNINGSYM
U$18: HEALTHYPIFIT
U$20: HEALTHYPIV5LOGO
U$22, U$27: PC_LOGO_ONELINE_ROUND

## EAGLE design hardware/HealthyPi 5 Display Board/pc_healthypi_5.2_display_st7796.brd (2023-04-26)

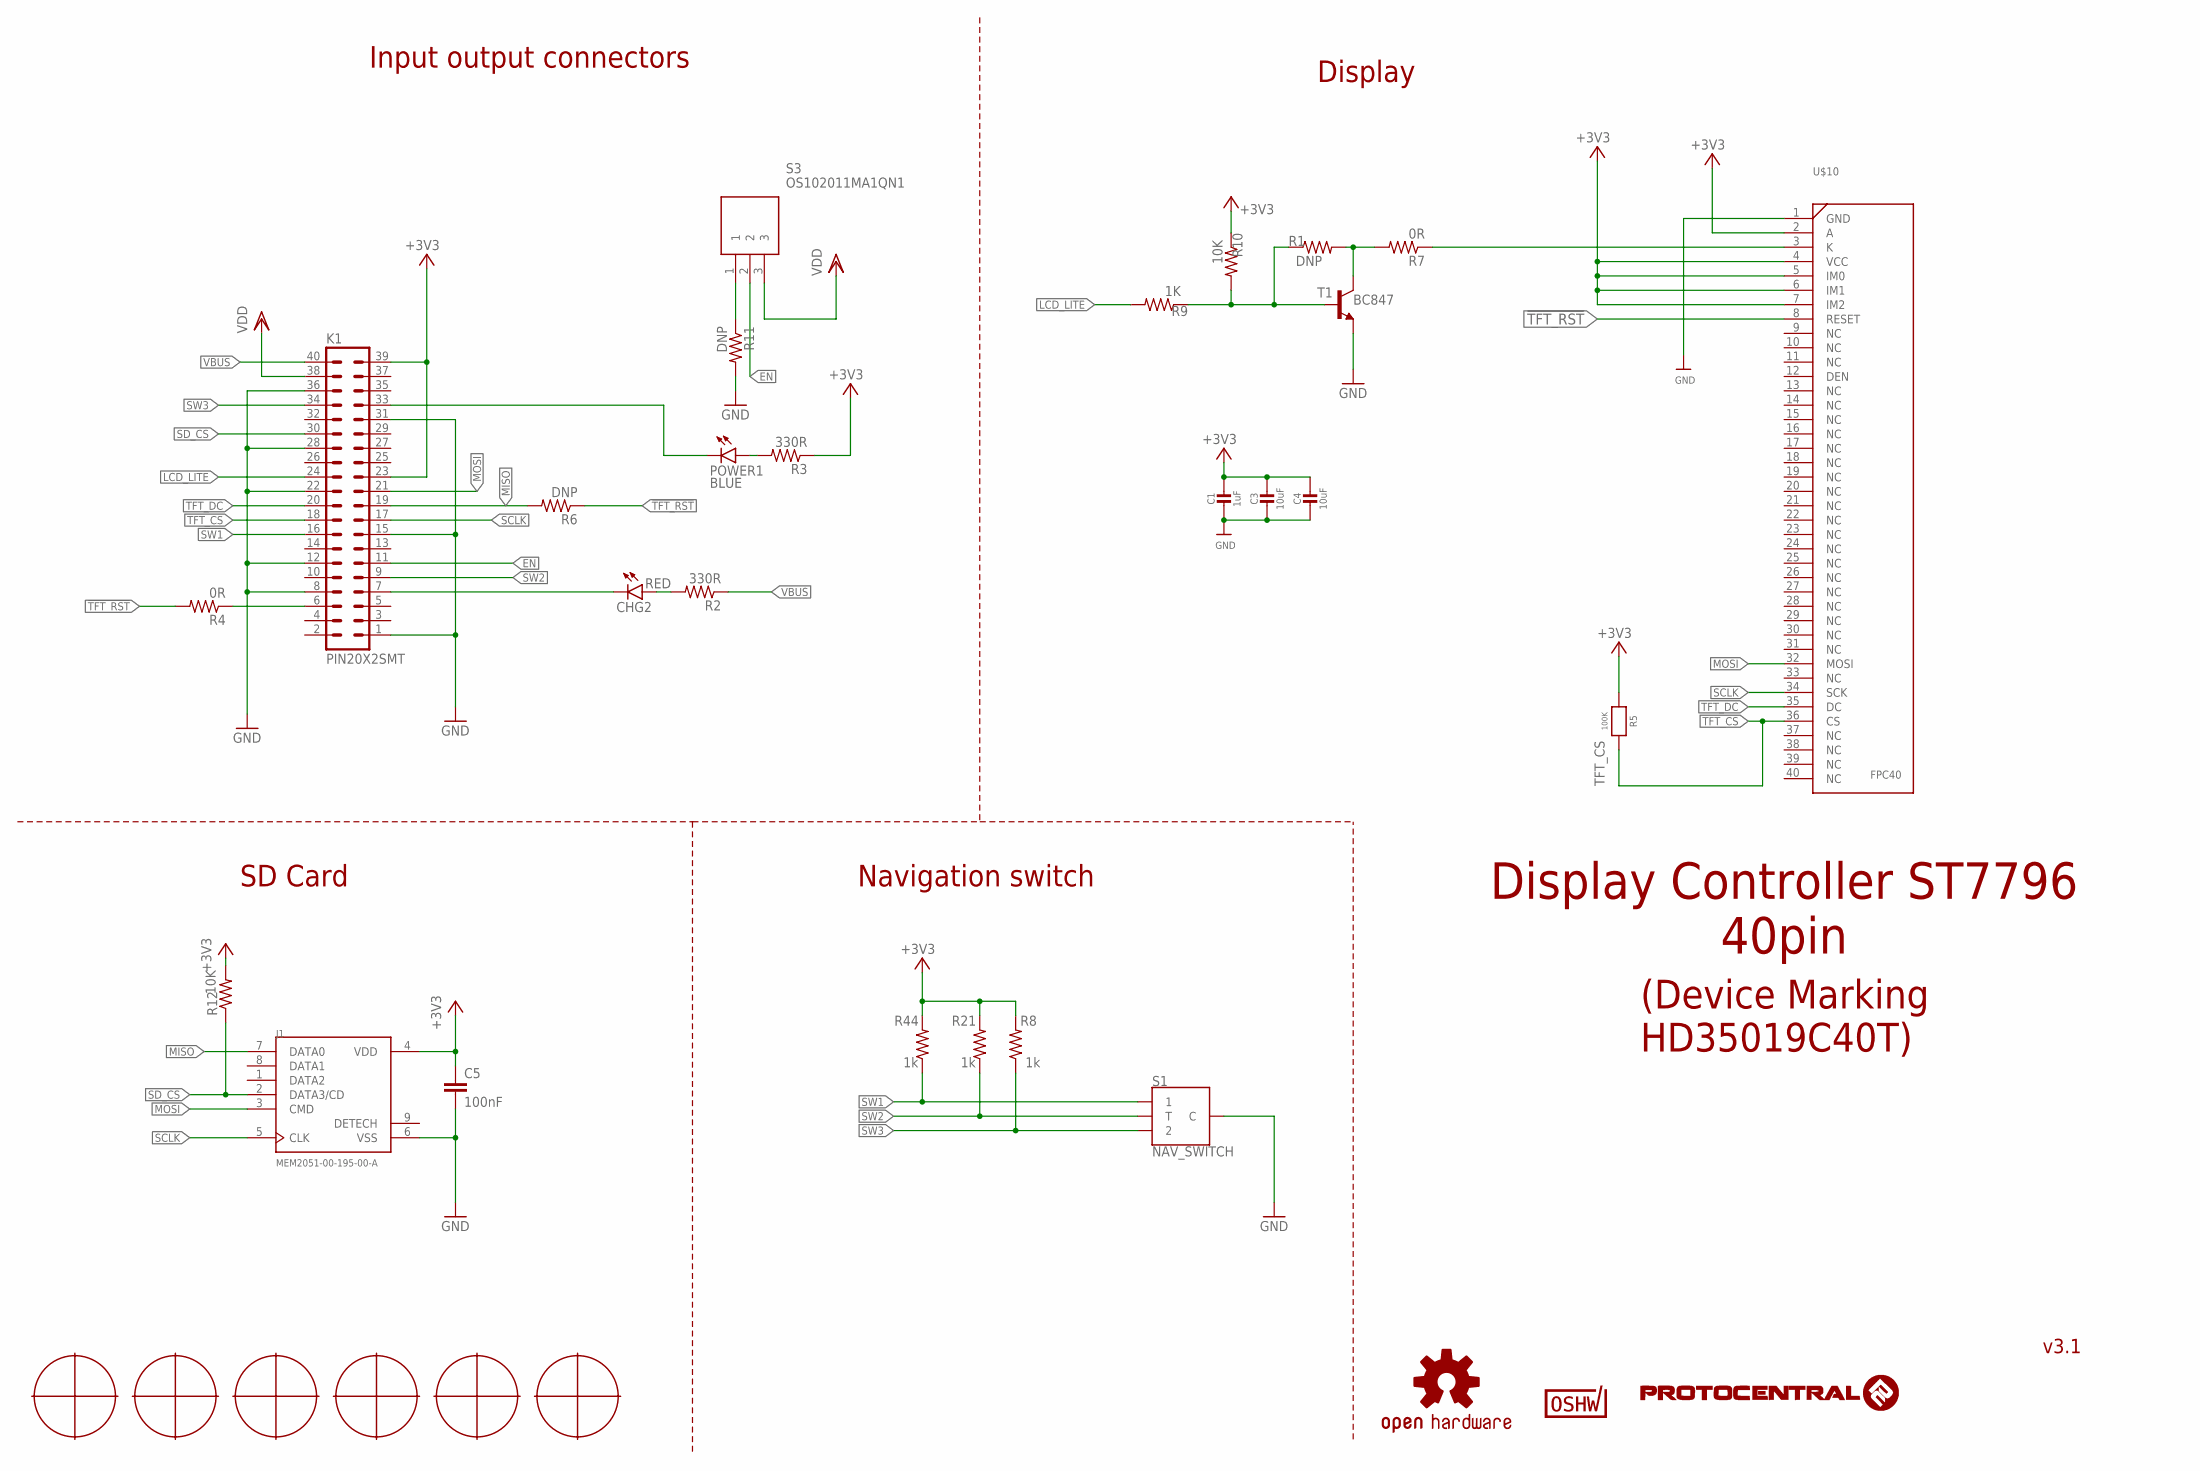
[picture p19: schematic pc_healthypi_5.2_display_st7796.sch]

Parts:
C1: 1uF; 0805-NO
C3, C4: 10uF; 0805-NO
C5: 100nF; C0402
CHG2: RED; CHIPLED_0603
J1: MEM2051-00-195-00-A; GCT_MEM2051-00-195-00-A
K1: PIN20X2SMT; 20X2SMT
POWER1: BLUE; CHIPLED_0603
R1, R6, R11: DNP; R0402
R2, R3: 330R; R0402
R4: 0R; R0402
R5: 100K; 0805-NO
R7: 0R; R0805
R8, R21, R44: 1k; 0402
R9: 1K; R0402
R10, R12: 10K; R0402
S1: NAV_SWITCH
S3: OS102011MA1QN1
T1: BC847; SOT23-BEC
U$1, U$3, U$7, U$8, U$23, U$25: FUDCIALPOINTS; FIDUCIALPOINTS
U$5: OSHW-LOGOM; OSHW-LOGO-M
U$10: FPC40; FPC40PIN
U$13: CERT-SMALL; CERT-SMALL-SILK

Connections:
!TFT_RST: R4.2, R6.1, U$10.8 (RESET)
+3V3: C1.1, C3.1, C4.1, C5.1, J1.4 (VDD), K1.23, K1.39, R3.1, R5.2, R8.2, R10.1, R12.2, R21.2, R44.2, U$10.2 (A), U$10.4 (VCC), U$10.5 (IM0), U$10.6 (IM1), U$10.7 (IM2)
EN: K1.11, S3.2
GND: C1.2, C3.2, C4.2, C5.2, J1.6 (VSS), K1.1, K1.8, K1.12, K1.15, K1.22, K1.28, K1.31, K1.36, R11.2, S1.C, T1.E, U$10.1 (GND)
LCD_LITE: K1.24, R9.2
LED1: K1.33, POWER1.C
MISO: J1.7 (DATA0), K1.19, R6.2
MOSI: J1.3 (CMD), K1.21, U$10.32 (MOSI)
unnamed: R1.2, R7.2, T1.C
unnamed: CHG2.C, K1.7
unnamed: K1.6, R4.1
unnamed: R7.1, U$10.3 (K)
unnamed: POWER1.A, R3.2
unnamed: CHG2.A, R2.2
unnamed: R11.1, S3.1
unnamed: R1.1, R9.1, R10.2, T1.B
SCLK: J1.5 (CLK), K1.17, U$10.34 (SCK)
SD_CS: J1.2 (DATA3/CD), K1.30, R12.1
SW1: K1.16, R44.1, S1.1
SW2: K1.9, R21.1, S1.T
SW3: K1.34, R8.1, S1.2
TFT_CS: K1.18, R5.1, U$10.36 (CS)
TFT_DC: K1.20, U$10.35 (DC)
VBUS: K1.40, R2.1
VDD: K1.38, S3.3

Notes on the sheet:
Display Controller ST7796 40pin
(Device Marking HD35019C40T)
Input output connectors
Display
SD Card
Navigation switch
v3.1

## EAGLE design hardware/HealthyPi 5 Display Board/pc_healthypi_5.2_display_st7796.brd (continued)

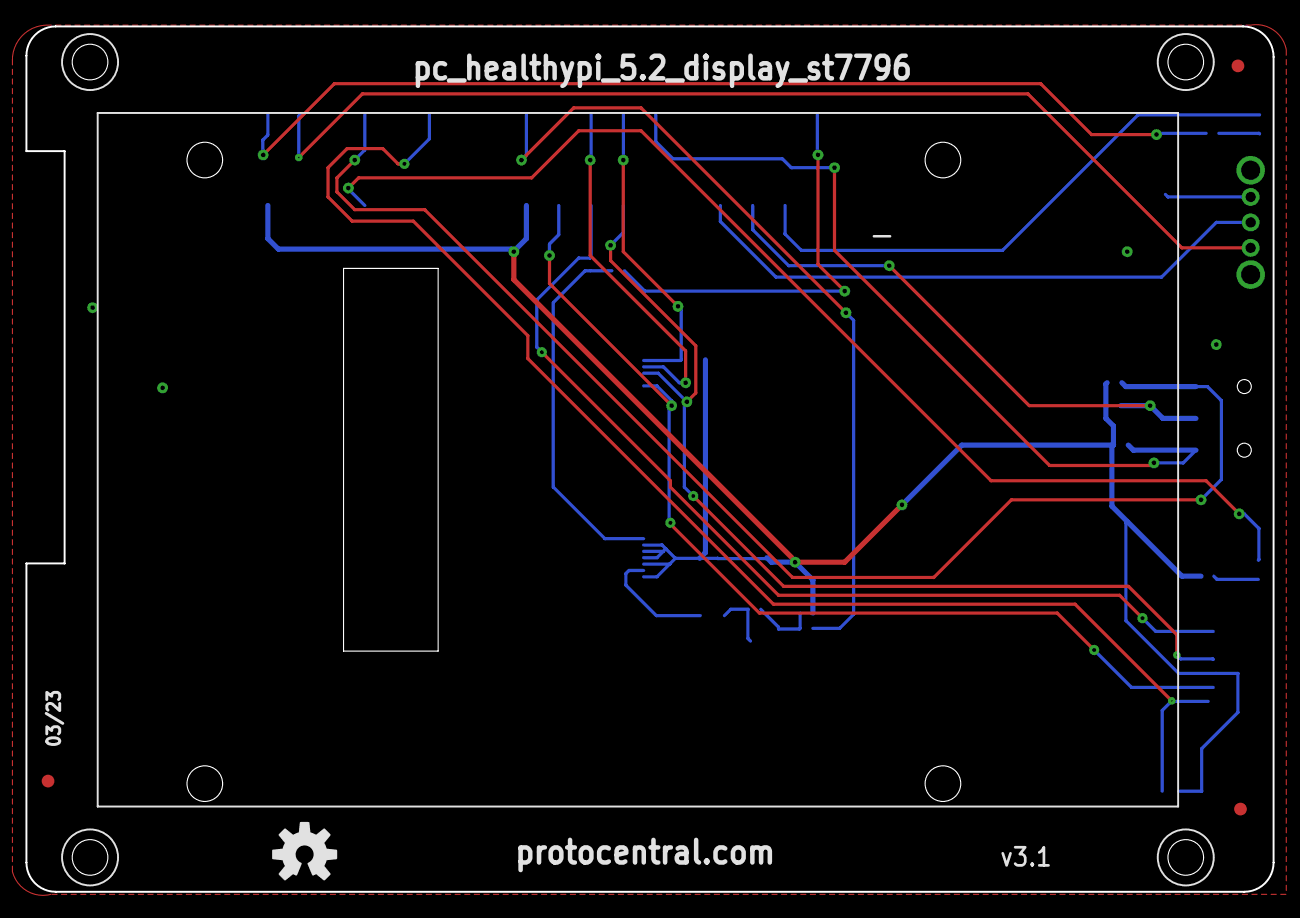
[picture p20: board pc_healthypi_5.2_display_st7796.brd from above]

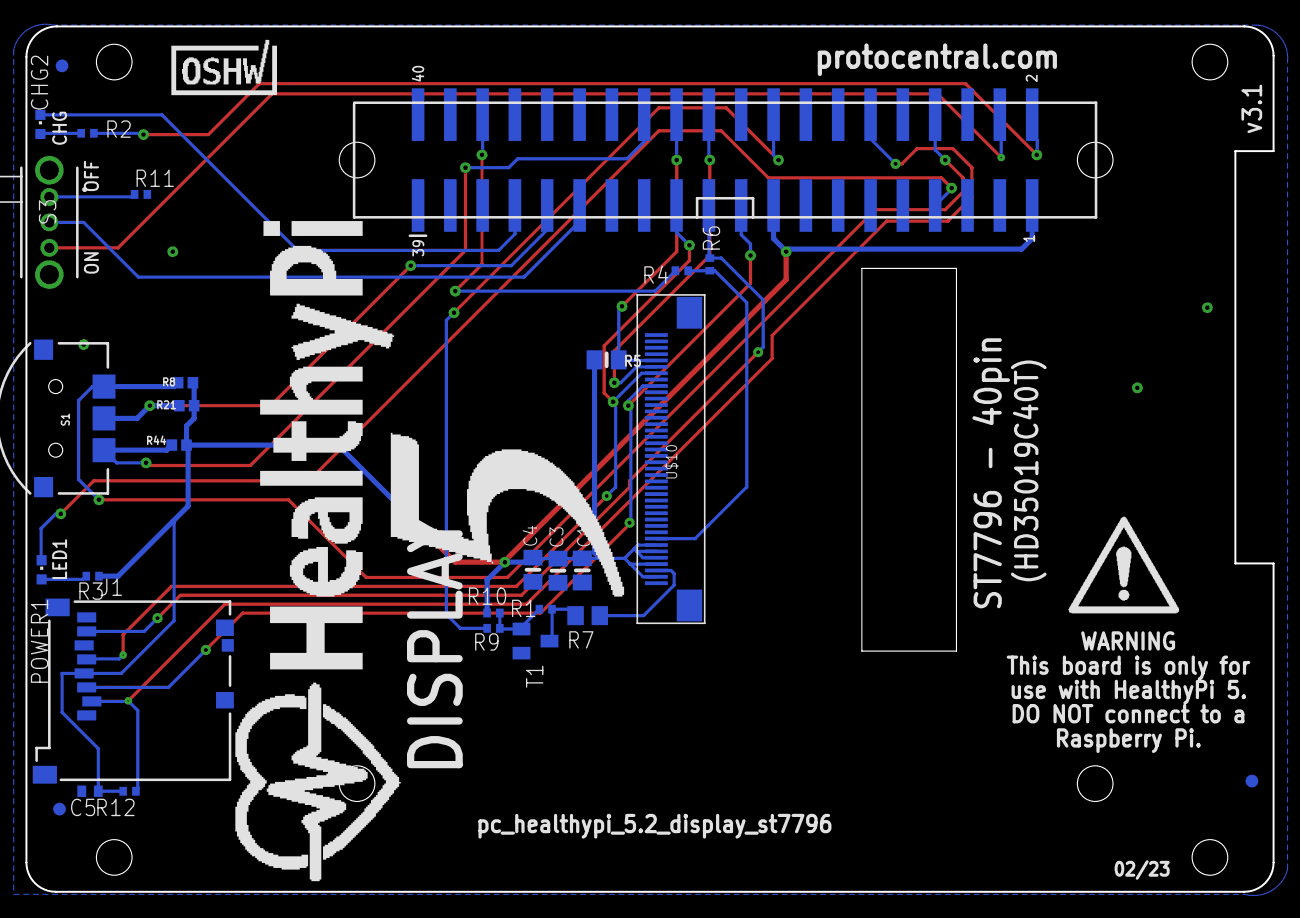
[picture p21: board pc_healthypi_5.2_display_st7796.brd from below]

Board: 2 copper layers, 98.0 x 68.0 mm, 36 parts (32 on the bottom side), 25 nets.

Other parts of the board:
U$9: WARNINGSYM
U$20: HEALTHYPIV5LOGO

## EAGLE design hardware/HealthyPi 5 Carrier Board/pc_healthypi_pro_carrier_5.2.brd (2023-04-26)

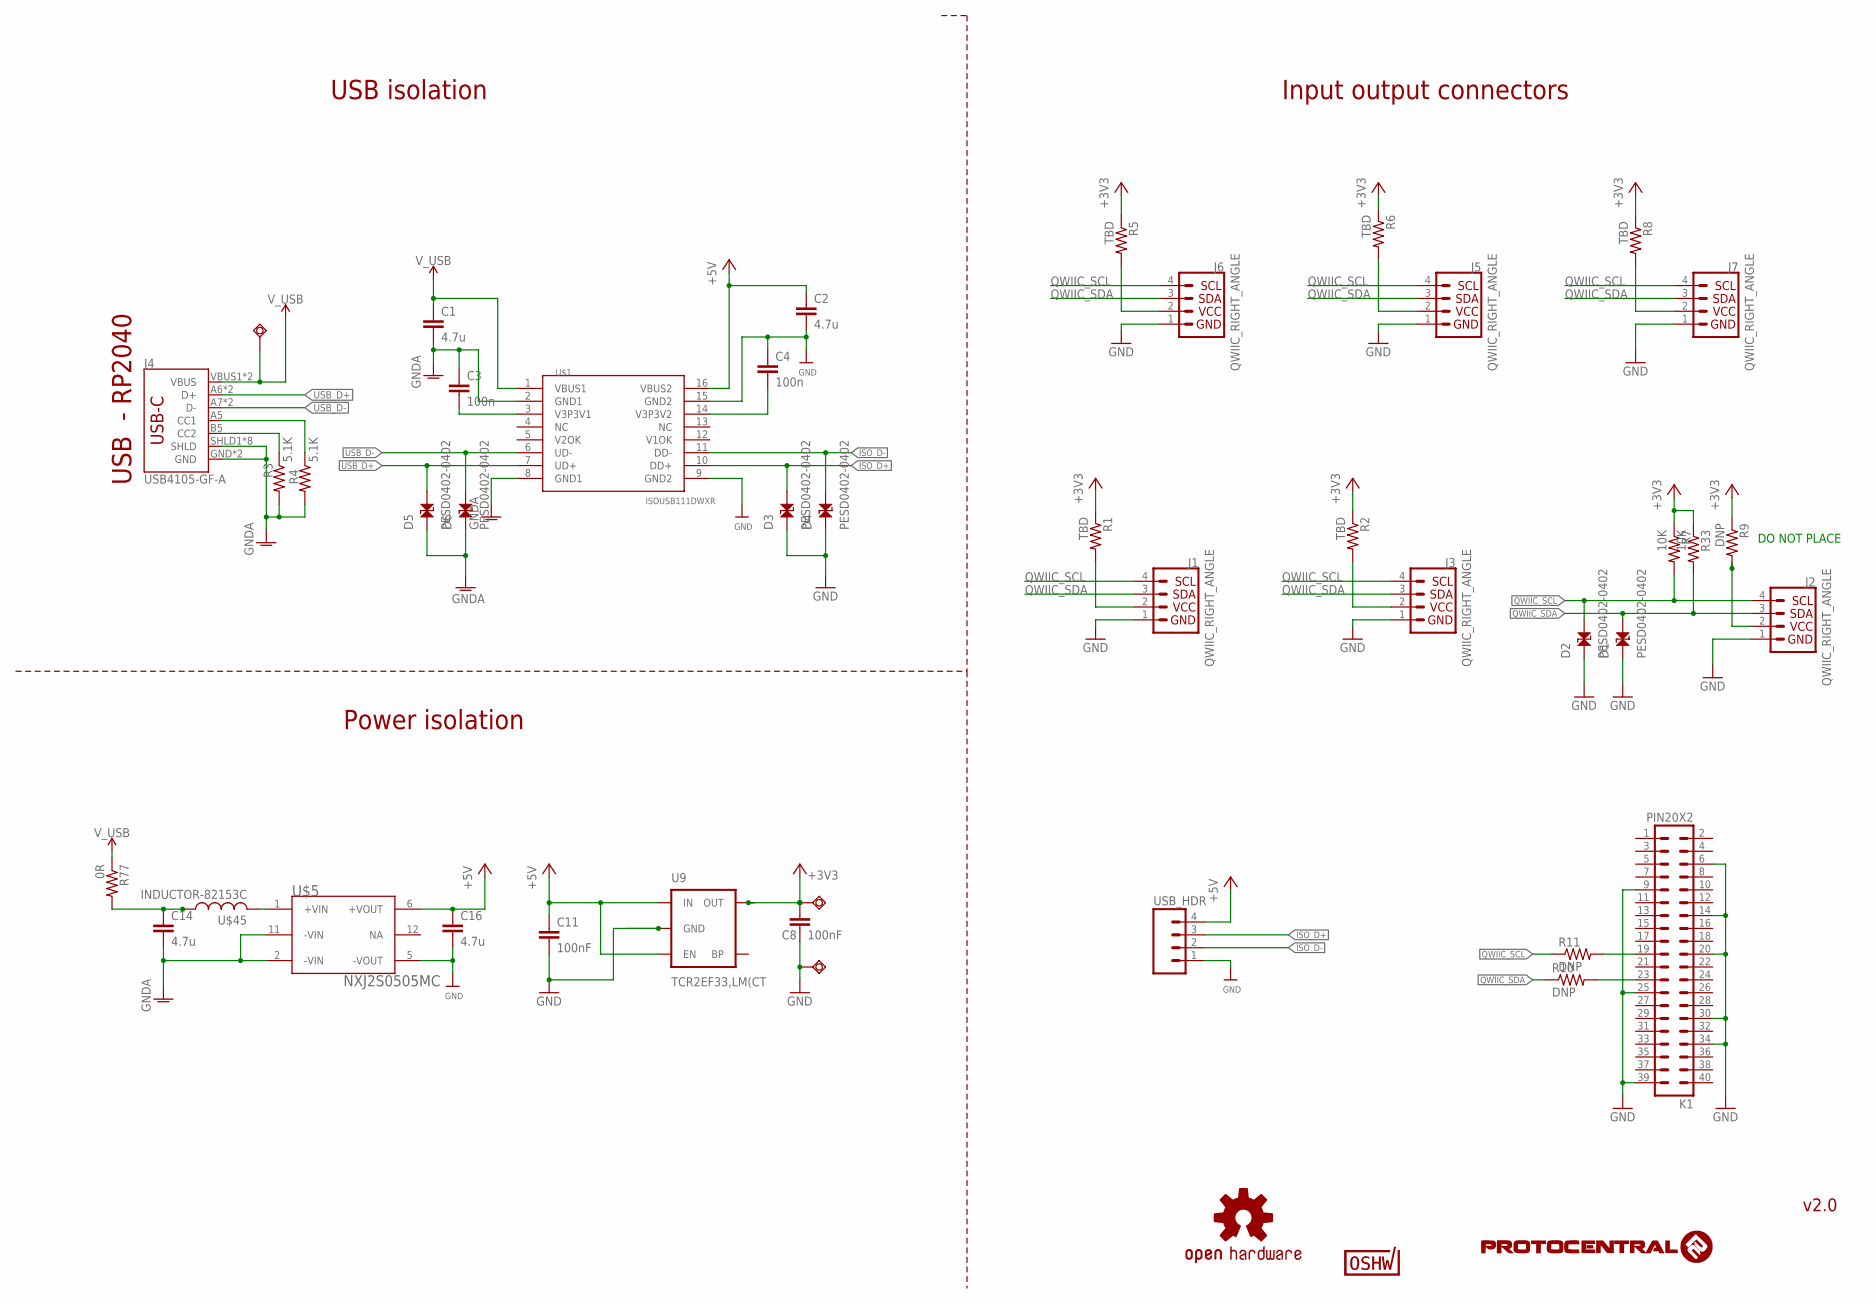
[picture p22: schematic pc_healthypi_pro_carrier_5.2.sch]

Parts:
C1, C2, C14, C16: 4.7u; C0805
C3, C4: 100n; C0402
C8, C11: 100nF; C0402
D1, D2, D3, D4, D5, D6: PESD0402-0402; 0402
J1, J2, J3, J5, J6, J7: QWIIC_RIGHT_ANGLE; JST04_1MM_RA
J4: USB4105-GF-A; USB-C-16P
K1: PIN20X2; PIN_20X2
R1, R2, R5, R6, R8: TBD; R0402
R3, R4: 5.1K; R0402
R7, R33: 10K; R0402
R9, R10, R11: DNP; R0402
R77: 0R; R0805
SWIO5, SWIO6: TPSQTP11R; TP11R
TP8: TPSQTP11R; TP11R
U9: TCR2EF33,LM(CT; SOT23-5
U$1: ISOUSB111DWXR; SSOP-16-5.85X7.5
U$5: NXJ2S0505MC
U$13: CERT-SMALL; CERT-SMALL-SILK
U$42: OSHW-LOGOM; OSHW-LOGO-M
U$45: INDUCTOR-82153C; INDUCTOR-8200
USB_HDR: M04LOCK_LONGPADS; 1X04_LOCK_LONGPADS

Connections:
+3V3: C8.1, R1.1, R2.1, R5.1, R6.1, R7.1, R8.1, R9.1, R33.1, SWIO5.TP, U9.5 (OUT)
+5V: C2.1, C11.1, C16.1, U9.1 (IN), U9.3 (EN), U$1.16 (VBUS2), U$5.6 (+VOUT), USB_HDR.4
GND: C2.2, C4.1, C8.2, C11.2, C16.2, D1.1, D2.1, D3.1, D4.1, J1.1, J2.1, J3.1, J5.1, J6.1, J7.1, K1.6, K1.9, K1.14, K1.20, K1.25, K1.30, K1.34, K1.39, SWIO6.TP, U9.2 (GND), U$1.9 (GND2), U$1.15 (GND2), U$5.5 (-VOUT), USB_HDR.1
GNDA: C1.2, C3.1, C14.2, D5.1, D6.1, J4.GND, J4.GND2 (GND), J4.SHLD1 (SHLD), J4.SHLD2 (SHLD), J4.SHLD3 (SHLD), J4.SHLD4 (SHLD), J4.SHLD5 (SHLD), J4.SHLD6 (SHLD), J4.SHLD7 (SHLD), J4.SHLD8 (SHLD), R3.2, R4.2, U$1.2 (GND1), U$1.8 (GND1), U$5.2 (-VIN), U$5.11 (-VIN)
ISO_D+: D3.2, U$1.10 (DD+), USB_HDR.3
ISO_D-: D4.2, U$1.11 (DD-), USB_HDR.2
unnamed: J1.2, R1.2
unnamed: J3.2, R2.2
unnamed: J6.2, R5.2
unnamed: J5.2, R6.2
unnamed: J7.2, R8.2
unnamed: J2.2, R9.2
unnamed: C3.2, U$1.3 (V3P3V1)
unnamed: C4.2, U$1.14 (V3P3V2)
unnamed: K1.23, R10.2
unnamed: K1.19, R11.2
unnamed: J4.B5 (CC2), R3.1
unnamed: J4.A5 (CC1), R4.1
unnamed: U$5.1 (+VIN), U$45.P$2 (2)
unnamed: C14.1, R77.2, U$45.P$1 (1)
QWIIC_SCL: D2.2, J1.4, J2.4, J3.4, J5.4, J6.4, J7.4, R7.2, R11.1
QWIIC_SDA: D1.2, J1.3, J2.3, J3.3, J5.3, J6.3, J7.3, R10.1, R33.2
USB_D+: D5.2, J4.A6 (D+), J4.B6 (D+), U$1.7 (UD+)
USB_D-: D6.2, J4.A7 (D-), J4.B7 (D-), U$1.6 (UD-)
V_USB: C1.1, J4.VBUS1 (VBUS), J4.VBUS2 (VBUS), R77.1, TP8.TP, U$1.1 (VBUS1)

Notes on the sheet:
USB - RP2040
DO NOT PLACE
USB isolation
Input output connectors
Power isolation
v2.0

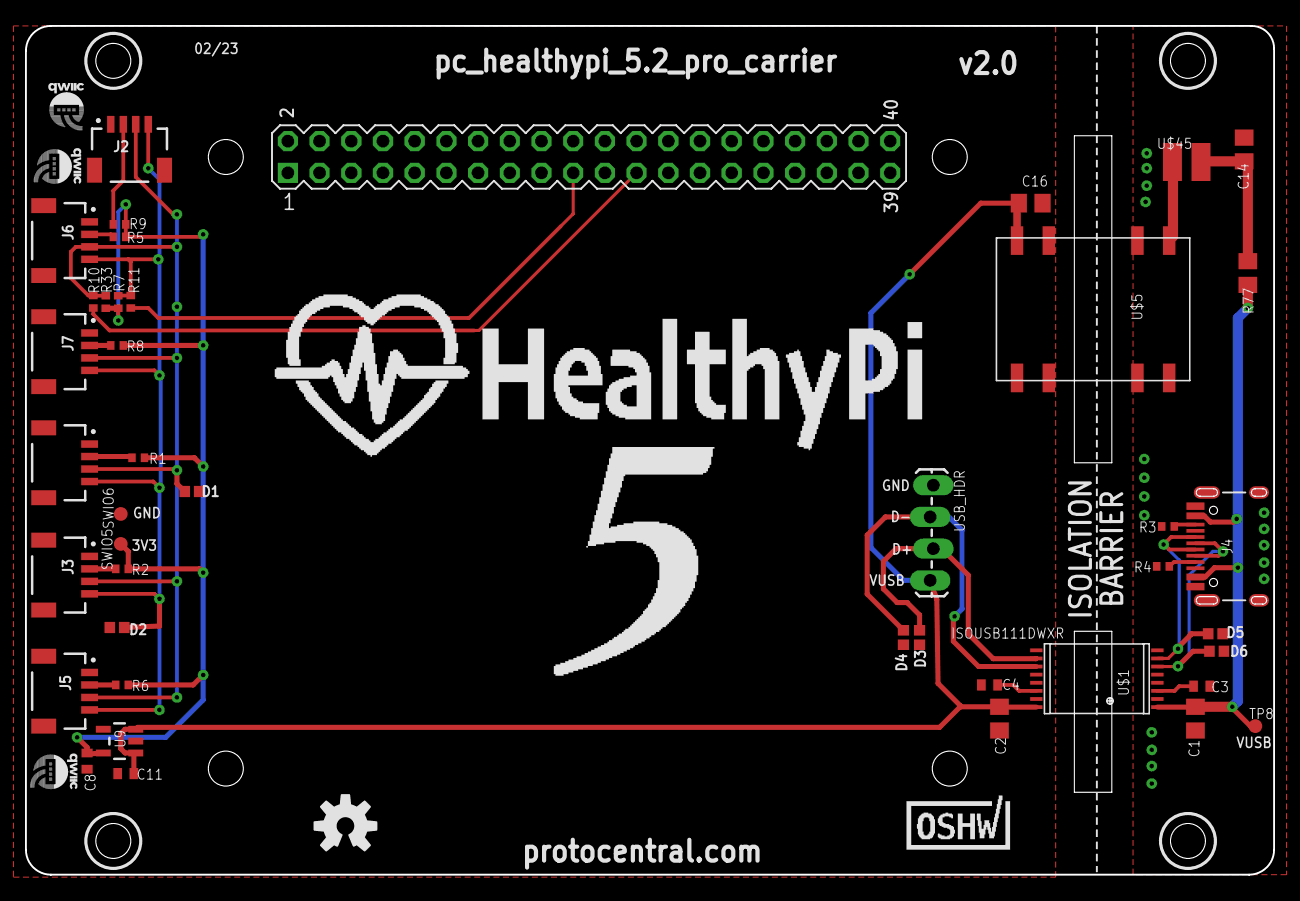
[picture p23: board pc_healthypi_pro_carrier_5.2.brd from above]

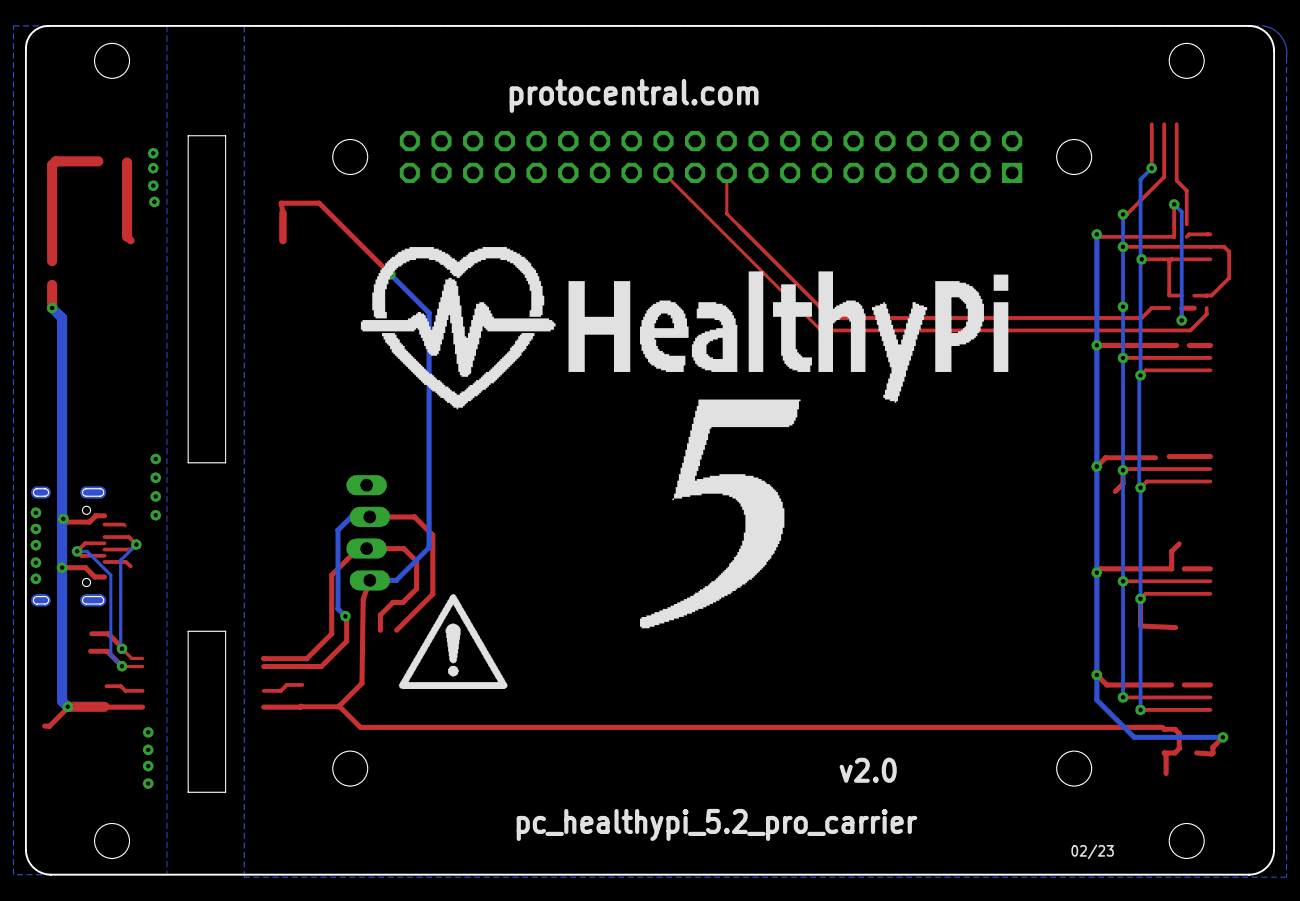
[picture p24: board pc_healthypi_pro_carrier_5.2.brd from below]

Board: 2 copper layers, 100.0 x 68.0 mm, 51 parts (2 on the bottom side), 25 nets.

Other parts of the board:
U$6, U$15, U$59: QWIIC#LABEL#FULL#M#PNG
U$7, U$20: HEALTHYPIV5LOGO
U$17: WARNINGSYM

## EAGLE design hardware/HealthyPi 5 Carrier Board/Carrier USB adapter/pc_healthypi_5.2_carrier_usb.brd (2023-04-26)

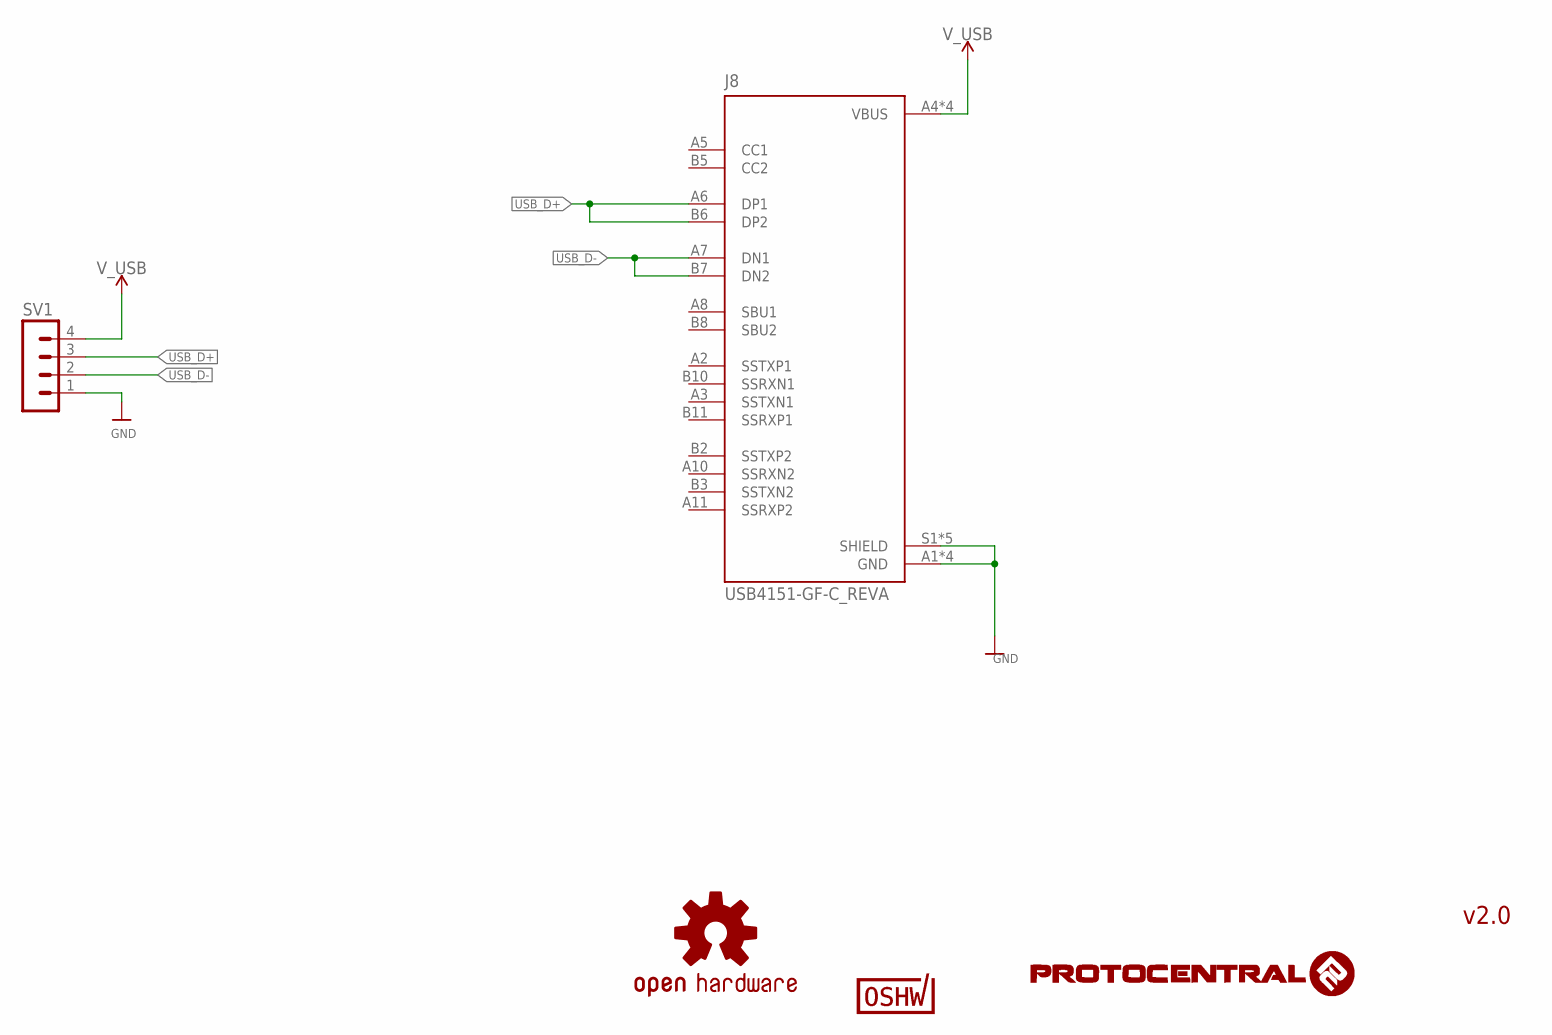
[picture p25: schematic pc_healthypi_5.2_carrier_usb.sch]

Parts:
J8: USB4151-GF-C_REVA; GCT_USB4151-GF-C_REVA
SV1: MA04-1
U$13: CERT-SMALL; CERT-SMALL-SILK
U$42: OSHW-LOGOM; OSHW-LOGO-M

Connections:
GND: J8.A1 (GND), J8.A12 (GND), J8.B1 (GND), J8.B12 (GND), J8.S1 (SHIELD), J8.S2 (SHIELD), J8.S3 (SHIELD), J8.S4 (SHIELD), J8.S5 (SHIELD), SV1.1
USB_D+: J8.A6 (DP1), J8.B6 (DP2), SV1.3
USB_D-: J8.A7 (DN1), J8.B7 (DN2), SV1.2
V_USB: J8.A4 (VBUS), J8.A9 (VBUS), J8.B4 (VBUS), J8.B9 (VBUS), SV1.4

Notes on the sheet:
v2.0


Board: 4 copper layers, 12.0 x 18.0 mm, 4 parts (1 on the bottom side), 4 nets.

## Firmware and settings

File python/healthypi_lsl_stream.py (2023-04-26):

""" Program to push HealthyPi 5 streaming data to a LSL stream
"""
import sys
import getopt
import serial

import time
from random import random as rand

from pylsl import StreamInfo, StreamOutlet, local_clock

""
"System Settings"
SERIAL_PORT_NAME = '/dev/tty.usbmodem2101'
SERIAL_BAUD = 115200
LSL_ENABLED = False

""
CESState_Init = 0
CESState_SOF1_Found = 1
CESState_SOF2_Found = 2
CESState_PktLen_Found = 3

"/*CES CMD IF Packet Format*"
CES_CMDIF_PKT_START_1   =   '0a'
CES_CMDIF_PKT_START_2   =   'fa'
CES_CMDIF_PKT_STOP      =   '0b' 

"CES CMD IF Packet Indices*"
CES_CMDIF_IND_LEN = 2
CES_CMDIF_IND_LEN_MSB = 3
CES_CMDIF_IND_PKTTYPE = 4
CES_CMDIF_PKT_OVERHEAD = 5

ecs_rx_state = CESState_Init

CES_Pkt_Data_Counter = [0] * 50
CES_Data_Counter = 0
CES_Pkt_ECG=bytearray()
CES_Pkt_Resp=bytearray()
CES_Pkt_PPG_IR=bytearray()

ser = serial.Serial(SERIAL_PORT_NAME,SERIAL_BAUD)

srate = 500
name = 'AU_BCI'
type = 'EEG'
n_channels = 6

if LSL_ENABLED==True:
    info = StreamInfo(name, type, n_channels, srate, 'float32', 'myuid34234')
    outlet = StreamOutlet(info)

def processRxChar(rxch):
    if ecs_rx_state==CESState_Init:
            #print(rxch)
        if rxch==CES_CMDIF_PKT_START_1:
                #print("Pkt Start")
                ecs_rx_state=CESState_SOF1_Found
        elif ecs_rx_state==CESState_SOF1_Found:
                if rxch==CES_CMDIF_PKT_START_2:
                    ecs_rx_state=CESState_SOF2_Found
                else:
                    ecs_rx_state=CESState_Init
        elif ecs_rx_state==CESState_SOF2_Found:
                ecs_rx_state = CESState_PktLen_Found
                CES_Pkt_Len = int(rxch,16) #int.from_bytes(rxch,'big')
                #print(CES_Pkt_Len)
                CES_Pkt_Pos_Counter = CES_CMDIF_IND_LEN
                CES_Data_Counter = 0
        elif ecs_rx_state==CESState_PktLen_Found:
                #print("Pkt Len Found")
                CES_Pkt_Pos_Counter+=1
                #print("Pkt Pos:") 
                #print(CES_Pkt_Pos_Counter)
                if CES_Pkt_Pos_Counter< CES_CMDIF_PKT_OVERHEAD:
                    if CES_Pkt_Pos_Counter==CES_CMDIF_IND_LEN_MSB:
                        CES_Pkt_Len = CES_Pkt_Len #(rxch<<8)|CES_Pkt_Len
                    elif CES_Pkt_Pos_Counter==CES_CMDIF_IND_PKTTYPE:
                        #rxch_bytes
                        CES_Pkt_PktType = int(rxch,16) #int.from_bytes(rxch,'big')
                elif CES_Pkt_Pos_Counter >= CES_CMDIF_PKT_OVERHEAD and CES_Pkt_Pos_Counter < CES_CMDIF_PKT_OVERHEAD+CES_Pkt_Len+1:
                    
                    if CES_Pkt_PktType==2:
                        CES_Data_Counter+=1
                        CES_Pkt_Data_Counter[CES_Data_Counter] = rxch
                else: 
                    "All data received"
                    if rxch==CES_CMDIF_PKT_STOP:
                        #print("Pkt Stop")
                        print(CES_Pkt_Len)

                        CES_Pkt_ECG.clear()
                        CES_Pkt_ECG.append(int(CES_Pkt_Data_Counter[0], 16))
                        CES_Pkt_ECG.append(int(CES_Pkt_Data_Counter[1], 16))
                        CES_Pkt_ECG.append(int(CES_Pkt_Data_Counter[2], 16))
                        CES_Pkt_ECG.append(int(CES_Pkt_Data_Counter[3], 16))

                        ecg_int_val=int.from_bytes(CES_Pkt_ECG,'little',signed=True)

                        CES_Pkt_PPG_IR.clear()
                        CES_Pkt_PPG_IR.append(int(CES_Pkt_Data_Counter[9], 16))
                        CES_Pkt_PPG_IR.append(int(CES_Pkt_Data_Counter[10], 16))
                        CES_Pkt_PPG_IR.append(int(CES_Pkt_Data_Counter[11], 16))
                        CES_Pkt_PPG_IR.append(int(CES_Pkt_Data_Counter[12],16))

                        ppg_int_val=int.from_bytes(CES_Pkt_PPG_IR,'little',signed=True)
                        #print(ppg_int_val)
                        if LSL_ENABLED==True:
                            lslsample=[(ppg_int_val*0.00001), (ppg_int_val*0.00001)]
                            outlet.push_sample(lslsample)
                            
                        #print(" ")

                        #print(CES_Pkt_PPG_IR)
                        #bytes_ppg_ir = int(CES_Pkt_PPG_IR.encode('hex'),16)
                        #bytes_ppg_ir = bytes(CES_Pkt_PPG_IR)
                        #ppg_int_val = int.from_bytes(bytes_ppg_ir, byteorder='big', signed=True)
                        #print(ppg_int_val)    

                        ecs_rx_state=CESState_Init
                    else:
                        ecs_rx_state=CESState_Init
    

while True:
    #try:
        ser_bytes = ser.read()

        #rxch=ser_bytes.decode('base64')
        rxch=bytes.hex(ser_bytes)
        #print(ser_bytes)
        #print(rxch)

        #ecsProcessData(ser_bytes)
        #print(ecs_rx_state)
        if ecs_rx_state==CESState_Init:
            #print(rxch)
            if rxch==CES_CMDIF_PKT_START_1:
                #print("Pkt Start")
                ecs_rx_state=CESState_SOF1_Found
        elif ecs_rx_state==CESState_SOF1_Found:
                if rxch==CES_CMDIF_PKT_START_2:
                    ecs_rx_state=CESState_SOF2_Found
                else:
                    ecs_rx_state=CESState_Init
        elif ecs_rx_state==CESState_SOF2_Found:
                ecs_rx_state = CESState_PktLen_Found
                CES_Pkt_Len = int(rxch,16) #int.from_bytes(rxch,'big')
                #print(CES_Pkt_Len)
                CES_Pkt_Pos_Counter = CES_CMDIF_IND_LEN
                CES_Data_Counter = 0
        elif ecs_rx_state==CESState_PktLen_Found:
                #print("Pkt Len Found")
                CES_Pkt_Pos_Counter+=1
                #print("Pkt Pos:") 
                #print(CES_Pkt_Pos_Counter)
                if CES_Pkt_Pos_Counter< CES_CMDIF_PKT_OVERHEAD:
                    if CES_Pkt_Pos_Counter==CES_CMDIF_IND_LEN_MSB:
                        CES_Pkt_Len = CES_Pkt_Len #(rxch<<8)|CES_Pkt_Len
                    elif CES_Pkt_Pos_Counter==CES_CMDIF_IND_PKTTYPE:
                        #rxch_bytes
                        CES_Pkt_PktType = int(rxch,16) #int.from_bytes(rxch,'big')
                elif CES_Pkt_Pos_Counter >= CES_CMDIF_PKT_OVERHEAD and CES_Pkt_Pos_Counter < CES_CMDIF_PKT_OVERHEAD+CES_Pkt_Len+1:
                    
                    if CES_Pkt_PktType==2:
                        CES_Data_Counter+=1
                        CES_Pkt_Data_Counter[CES_Data_Counter] = rxch
                else: 
                    "All data received"
                    if rxch==CES_CMDIF_PKT_STOP:
                        #print("Pkt Stop")
                        print(CES_Pkt_Len)

                        CES_Pkt_ECG.clear()
                        CES_Pkt_ECG.append(int(CES_Pkt_Data_Counter[0], 16))
                        CES_Pkt_ECG.append(int(CES_Pkt_Data_Counter[1], 16))
                        CES_Pkt_ECG.append(int(CES_Pkt_Data_Counter[2], 16))
                        CES_Pkt_ECG.append(int(CES_Pkt_Data_Counter[3], 16))

                        ecg_int_val=int.from_bytes(CES_Pkt_ECG,'little',signed=True)

                        CES_Pkt_PPG_IR.clear()
                        CES_Pkt_PPG_IR.append(int(CES_Pkt_Data_Counter[9], 16))
                        CES_Pkt_PPG_IR.append(int(CES_Pkt_Data_Counter[10], 16))
                        CES_Pkt_PPG_IR.append(int(CES_Pkt_Data_Counter[11], 16))
                        CES_Pkt_PPG_IR.append(int(CES_Pkt_Data_Counter[12],16))

                        ppg_int_val=int.from_bytes(CES_Pkt_PPG_IR,'little',signed=True)
                        #print(ppg_int_val)
                        if LSL_ENABLED==True:
                            lslsample=[(ppg_int_val*0.00001), (ppg_int_val*0.00001)]
                            outlet.push_sample(lslsample)
                            
                        #print(" ")

                        #print(CES_Pkt_PPG_IR)
                        #bytes_ppg_ir = int(CES_Pkt_PPG_IR.encode('hex'),16)
                        #bytes_ppg_ir = bytes(CES_Pkt_PPG_IR)
                        #ppg_int_val = int.from_bytes(bytes_ppg_ir, byteorder='big', signed=True)
                        #print(ppg_int_val)    

                        ecs_rx_state=CESState_Init
                    else:
                        ecs_rx_state=CESState_Init

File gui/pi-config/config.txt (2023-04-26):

# For more options and information see
# http://rpf.io/configtxt
# Some settings may impact device functionality. See link above for details

# uncomment if you get no picture on HDMI for a default "safe" mode
#hdmi_safe=1

# uncomment this if your display has a black border of unused pixels visible
# and your display can output without overscan
#disable_overscan=1

# uncomment the following to adjust overscan. Use positive numbers if console
# goes off screen, and negative if there is too much border
#overscan_left=16
#overscan_right=16
#overscan_top=16
#overscan_bottom=16

# uncomment to force a console size. By default it will be display's size minus
# overscan.
#framebuffer_width=1280
#framebuffer_height=720

# uncomment if hdmi display is not detected and composite is being output
#hdmi_force_hotplug=1

# uncomment to force a specific HDMI mode (this will force VGA)
#hdmi_group=1
#hdmi_mode=1

# uncomment to force a HDMI mode rather than DVI. This can make audio work in
# DMT (computer monitor) modes
#hdmi_drive=2

# uncomment to increase signal to HDMI, if you have interference, blanking, or
# no display
#config_hdmi_boost=4

# uncomment for composite PAL
#sdtv_mode=2

#uncomment to overclock the arm. 700 MHz is the default.
#arm_freq=800

# Uncomment some or all of these to enable the optional hardware interfaces
#dtparam=i2c_arm=on
#dtparam=i2s=on
#dtparam=spi=on

# Uncomment this to enable infrared communication.
#dtoverlay=gpio-ir,gpio_pin=17
#dtoverlay=gpio-ir-tx,gpio_pin=18

# Additional overlays and parameters are documented /boot/overlays/README

# Enable audio (loads snd_bcm2835)
dtparam=audio=on
enable_uart=1

[pi4]
# Enable DRM VC4 V3D driver on top of the dispmanx display stack
dtoverlay=vc4-fkms-v3d
max_framebuffers=2

[all]
#dtoverlay=vc4-fkms-v3d
dtoverlay=dwc2
dtoverlay=pi3-disable-bt
dtoverlay=disable-bt

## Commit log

2023-04-26 Initial public commit
    [HealthyPi 5 - Enclosure - Bottom.stl, HealthyPi 5 - Enclosure - Top.stl, config.txt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]
2023-05-17 Plot with fixed scale in mV
    [gui.pde]
2023-08-16 Added SpO2 HR, RR fields from device
2024-12-02 Added schematics upto HealthyPi 5.7
    [pc_healthypi_5.3.brd, pc_healthypi_5.3.sch, pc_healthypi_5.5.brd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]
2026-07-25 Replace clinical-grade wording with high-precision in README
    HealthyPi 5 is not a medical device, so avoid phrasing that implies a
    clinical or medical grade. Describe the front ends by their actual
    resolution instead.

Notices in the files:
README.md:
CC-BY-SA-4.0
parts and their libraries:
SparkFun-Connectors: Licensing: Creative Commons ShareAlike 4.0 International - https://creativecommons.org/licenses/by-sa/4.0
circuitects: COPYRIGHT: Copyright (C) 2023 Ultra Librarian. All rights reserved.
